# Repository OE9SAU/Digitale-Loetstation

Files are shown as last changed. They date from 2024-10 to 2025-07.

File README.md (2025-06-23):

# Digitale Lötstation mit ATtiny 84 v3

Soldering Unit for Weller RT solder tips.<br>
PCB design by OE9SAU <br>
µC-Code and STL-Desing by OE1CGS [http://www.oe1cgs.at/smd-loetstation/] <br>

v3: Add SK55 for reverse polarity protection

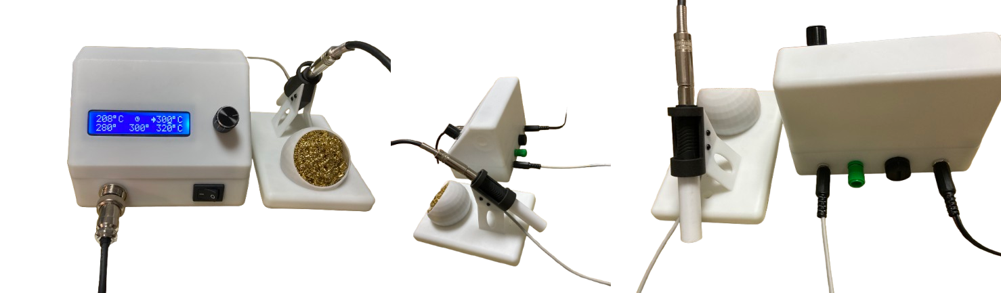
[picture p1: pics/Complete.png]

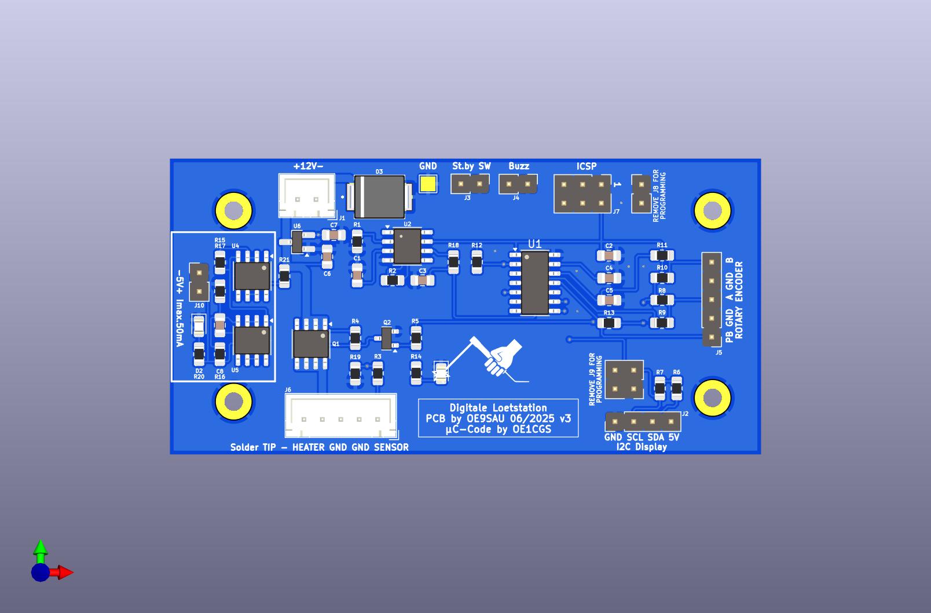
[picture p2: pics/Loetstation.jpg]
SMD-Loetstation

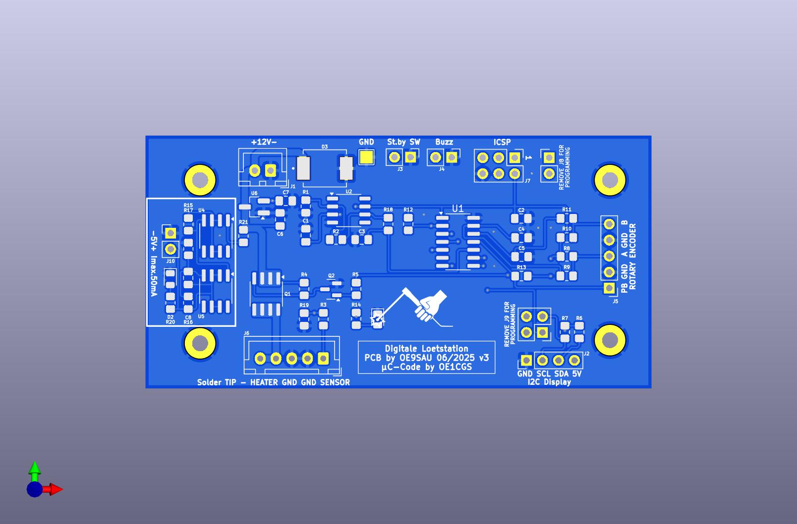
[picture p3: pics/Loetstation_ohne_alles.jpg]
SMD-Loetstation

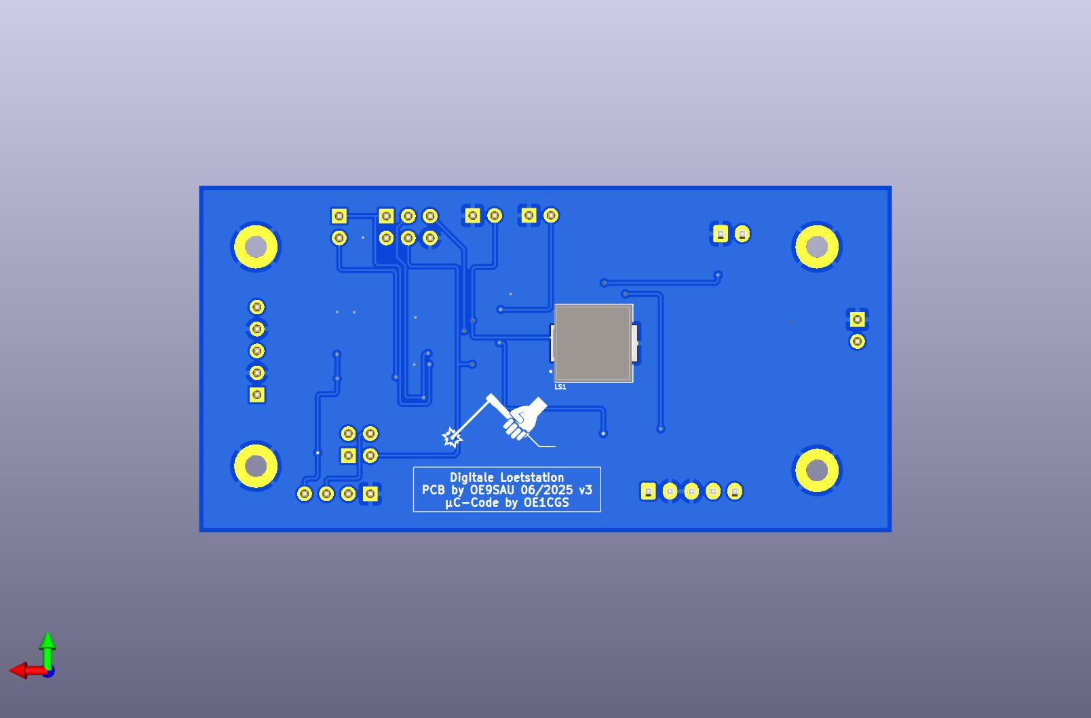
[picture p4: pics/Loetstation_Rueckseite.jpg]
SMD-Loetstation


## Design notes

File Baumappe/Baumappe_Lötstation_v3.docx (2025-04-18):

Baumappe «digitale Lötstation»


1.) Aufbau

Die Lötstation versorgt Lötspitzen der RT-Serie von Weller mit einer PWM-getakteten 12V-Gleichspannung. Das Taktverhältnis wird über die Stellgrößen einer PID-Regelung und der Lötspitzentemperatur, als Regelgröße, gebildet. Der in die Lötspitze integrierte Sensor ermöglicht eine schnelle und direkte Temperaturmessung.

Ein Drehschalter und ein 16x2-LCD mit I2C-Schnittstelle dienen zur Bedienung und Anzeige. Eine Lötspitzenhalterung mit Micro-Schalter aktiviert den Standby-Modus (60°C), um die Lebensdauer der Spitze zu erhöhen. Beim Entnehmen kehrt die Solltemperatur sofort zurück, was auch akustisch signalisiert wird.

Die Steuerung erfolgt über einen ATtiny84. Ein OPA 336V verstärkt die Sensorspannung (680-fach) auf 0 bis 5V für den Mikrocontroller. Der IRF 7416 MOSFET mit einem IRLML2060 als Gate-Treiber, versorgt die Lötspitze mit dem PWM-Signal.

NIEMALS DIE LÖTSPITZE OHNE J8 BETREIBEN!

Die Station benötigt 12V DC bei 3-4A und kann mobil (z. B. Autobatterie) oder stationär mit einem 12V/50W-Netzteil betrieben werden. Eine 4A-Schmelzsicherung bietet Schutz.

2.) Firmware
Die Firmware wurde mit der Arduino IDE für den ATtiny84 von OE1CGS entwickelt. Der Mikrocontroller läuft mit dem internen 1-MHz-RC-Oszillator.

Benötigte Bibliotheken:

- TinyWireM.h (I2C-Master für LCD)
- LiquidCrystal_I2C.h (Display-Steuerung)
- EEPROM.h (Speicherung von Einstellungen)

Der Drehschalter wird Interrupt-gesteuert und als Zustandsmaschine nach Ben Buxton interpretiert.

Funktionen:

- Temperaturregelung per PID (Intervall: 200ms, PWM mit 492Hz)
- Dynamische Anzeige und Einstellung von Parametern
- Standby-Erkennung und automatische Aktivierung
- Speicherung vordefinierter Temperaturen
- Sicherheitsabschaltung bei fehlerhaften Sensordaten (z. B. gelockerte Lötspitze)

3.) Regelungsparameter
Um die Regelungsparameter zu optimieren, wurden an einer Lötspitze vom Typ RT2 umfangreiche Messungen durchgeführt. Dabei wurde die Temperatur in Intervallen von 200 Millisekunden gemessen, zu welchem Zweck die Heizung für jeweils 10 ms ausgeschalten wurde. Damit ergibt sich eine mittlere Heizdauer von 95%.

Diese und weitere Messungen dienten der Kalibrierung eines Simulationsmodells für das Regelverhalten. Eine wesentliche Schlussfolgerung aus den Simulationen war, dass zwar ein einfacher P-Regler für die Lötstation ausreichend wäre, ein PID-Regler aber speziell im Hinblick auf eine rasche Verfügbarkeit (Aufheizphase) überlegen ist.

Die, durch die Simulationen ermittelten Regelungsparameter wurden in die Firmware übernommen und danach im praktischen Einsatz noch etwas adaptiert.

Damit benötigt die Spitze zur Aufheizung von Raumtemperatur auf 260°C nur 3,8 Sekunden; auf 300°C sind es 4,2 s.

Die Regelung hält die Temperatur der unbelasteten Spitze zuverlässig innerhalb +/-2°C. Beim Löten von bedrahteten Bauteilen (THT) sinkt die angezeigte Temperatur nur kurzfristig etwas ab und ist innert einer Sekunde wieder auf der Soll-Temperatur.

4.) Bedienung

Nach dem Einschalten zeigt das Display kurz einen Begrüßungstext und wechselt dann zum Standardschirm. Dort werden die aktuelle Lötspitzentemperatur, der Sollwert und ein Standby-Symbol angezeigt. Im Standby-Modus wird die Temperatur auf 60°C geregelt, um Energie zu sparen und die Lebensdauer der Lötspitze zu verlängern.

Die Solltemperatur kann über drei voreingestellte Werte (220°C, 260°C, 300°C) oder manuell in 1°C-Schritten angepasst werden. Änderungen erfolgen durch Drehen und Drücken des Drehschalters. Die Vorgabewerte lassen sich im Bereich von 60°C bis 400°C individuell speichern.

Beim Einschalten können durch Gedrückt halten des Drehschalters zusätzliche Parameter wie die Vorgabewerte und das akustische Signal angepasst werden. Nach dem Verlassen des Einstellungsmenüs bleiben alle Änderungen im Speicher erhalten.

Bei einem Notstopp durch fehlende Sensordaten erfolgt eine Warnung, und die Lötstation muss neu gestartet werden.

Auf der Rückseite des Geräts befindet sich neben den Anschlüssen für die Stromversorgung und den Standby-Taster sowie dem Sicherungs-halter auch eine Erdungsbuchse. Über diese kann beim Löten die Lötspitze auf das gemeinsame Massepotential gelegt werden. Der Anschluss erfolgt durch einen üblichen 4 mm Bananenstecker.

Schaltplan:

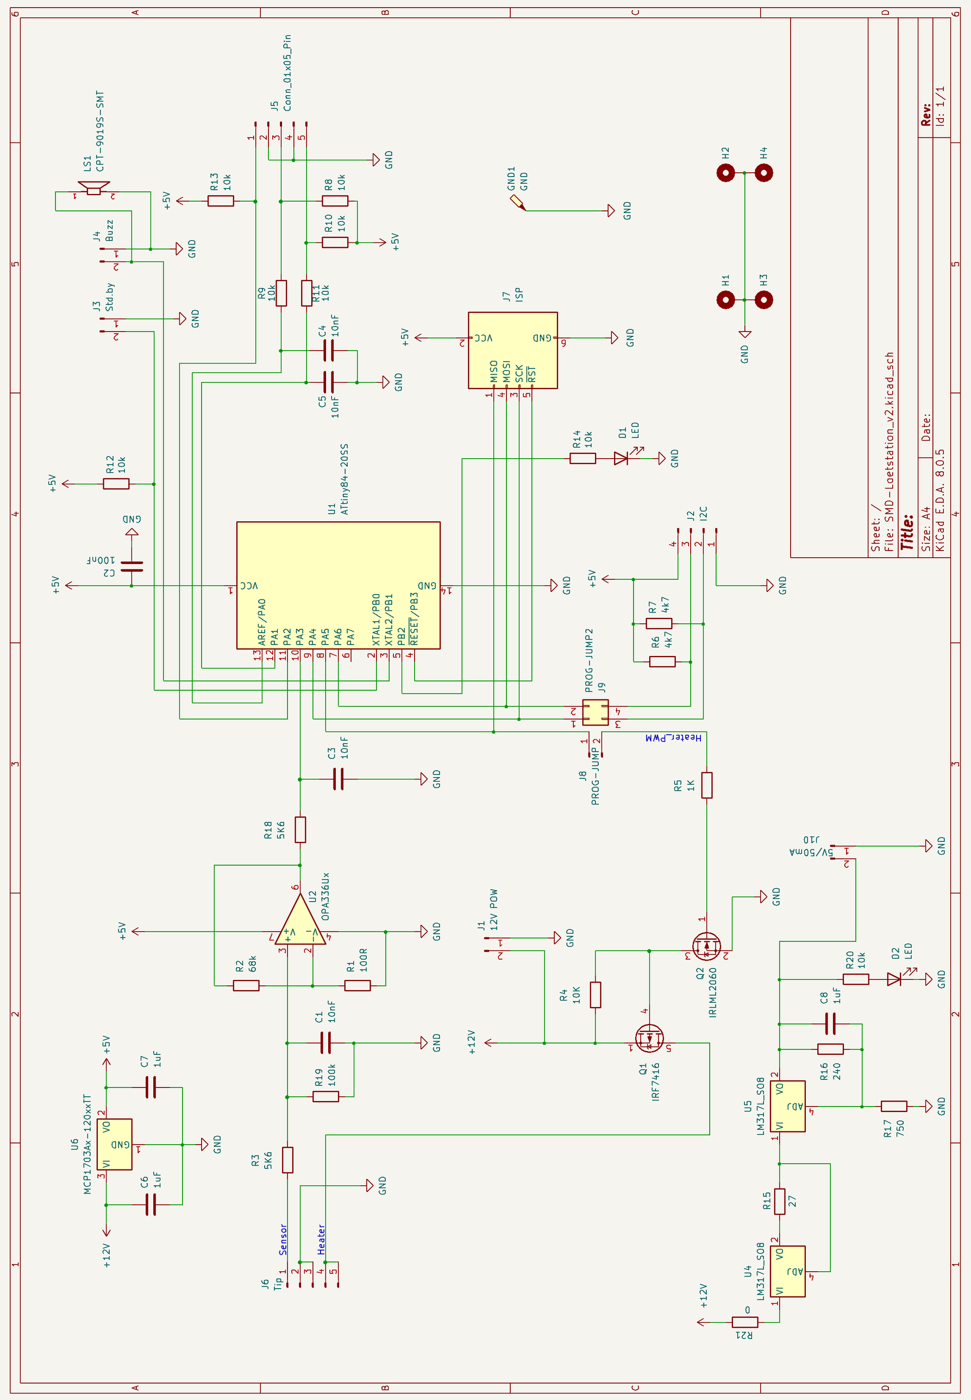
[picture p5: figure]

Bestückungsplan

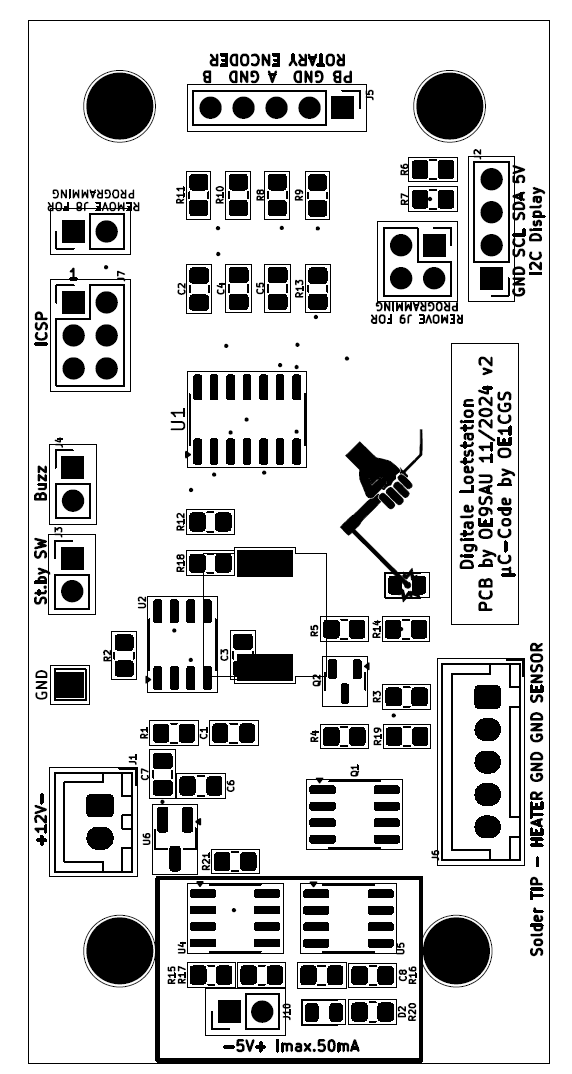
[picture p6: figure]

Stückliste:

Bezeichner | Stückzahl | Bezeichnung
R4,R12,R10,R8,R9,R14,R20,R11,R13 | 9 | 10k
C3,C5,C1,C4 | 4 | 10nF
R3,R18 | 2 | 5K6
R15 | 1 | 27R
R17 | 1 | 750R
J2 | 1 | I2C
R21 | 1 | 0R
R5 | 1 | 1K
Q2 | 1 | IRLML2060
R19 | 1 | 100k
J8 | 1 | PROG-JUMP
J4 | 1 | Buzz
J7 | 1 | ISP
U6 | 1 | MCP1703Ax-120xxTT
U5,U4 | 2 | LM317L_SO8
J1 | 1 | 12V POW
U2 | 1 | OPA336Ux
Q1 | 1 | IRF7416
J10 | 1 | 5V/50mA
R7,R6 | 2 | 4k7
C7,C8,C6 | 3 | 1uF
R2 | 1 | 68k
R1 | 1 | 100R
D1,D2 | 2 | LED
R16 | 1 | 240R
J3 | 1 | Std.by
U1 | 1 | ATtiny84-20SS
J5 | 1 | Conn_01x05_Pin
J6 | 1 | Tip
C2 | 1 | 100nF
J9 | 1 | PROG-JUMP2
Rückseite
LS1 | 1 | CPT-9019S-SMT

Bilder Aufbau:

0.65m Kabel LiYY 4x0.25 (UNITRONIC AMAZON)

Funktion | 4x0.25 | Buchse 4polig | PCB Solder TIP Plug
Sensor | gelb | 1 | 1 / gelb
| | 2 | 2 / leer
GND | weiss | 3 | 3 / schwarz
HEATER | braun/grün | 4 | 4 / braun
| | | 5 / leer

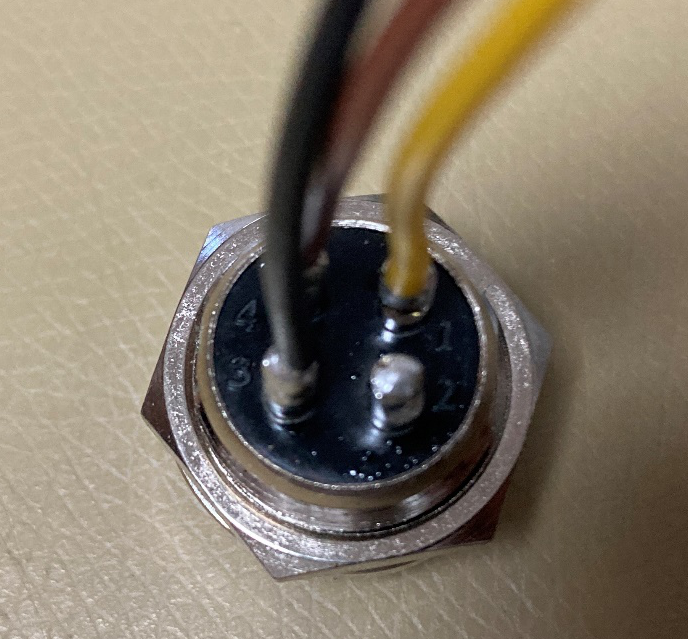
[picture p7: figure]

4 1 3 2

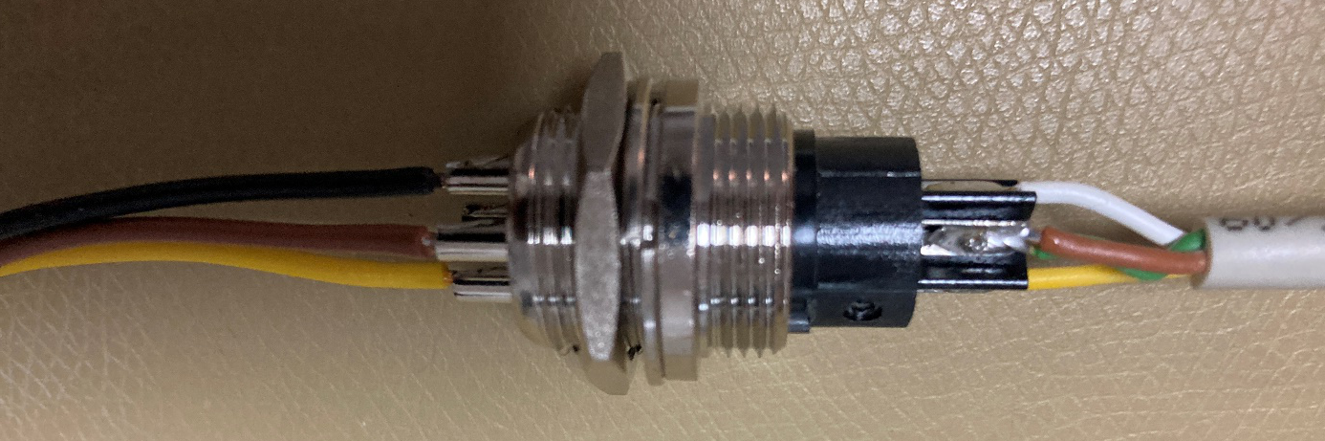
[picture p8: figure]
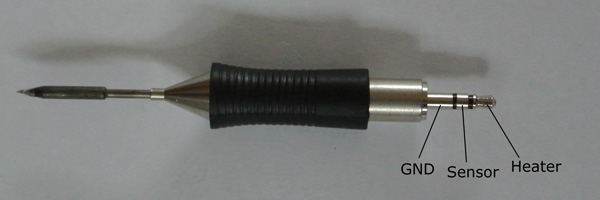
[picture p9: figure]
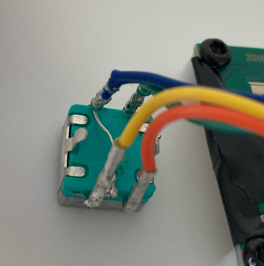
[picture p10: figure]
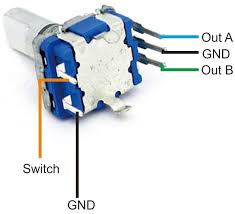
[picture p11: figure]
Rotary encoder not working - General Electronics - Arduino Forum
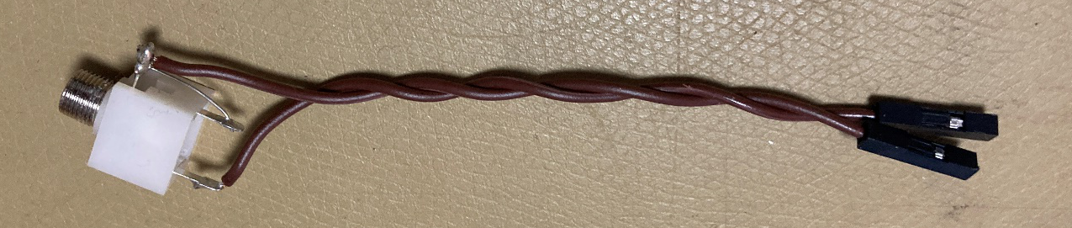
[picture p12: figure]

Wichtig: Brücke

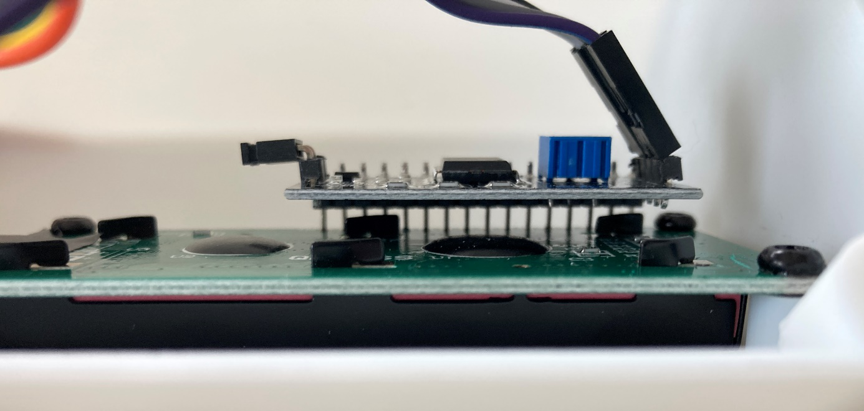
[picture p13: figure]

I2C-Adapter mit dem größtmöglichen (https://www.google.com/search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) Abstand zum LCD anlöten

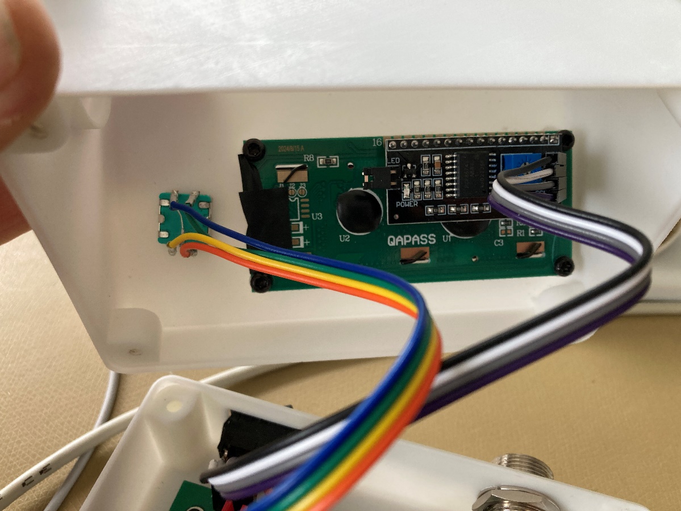
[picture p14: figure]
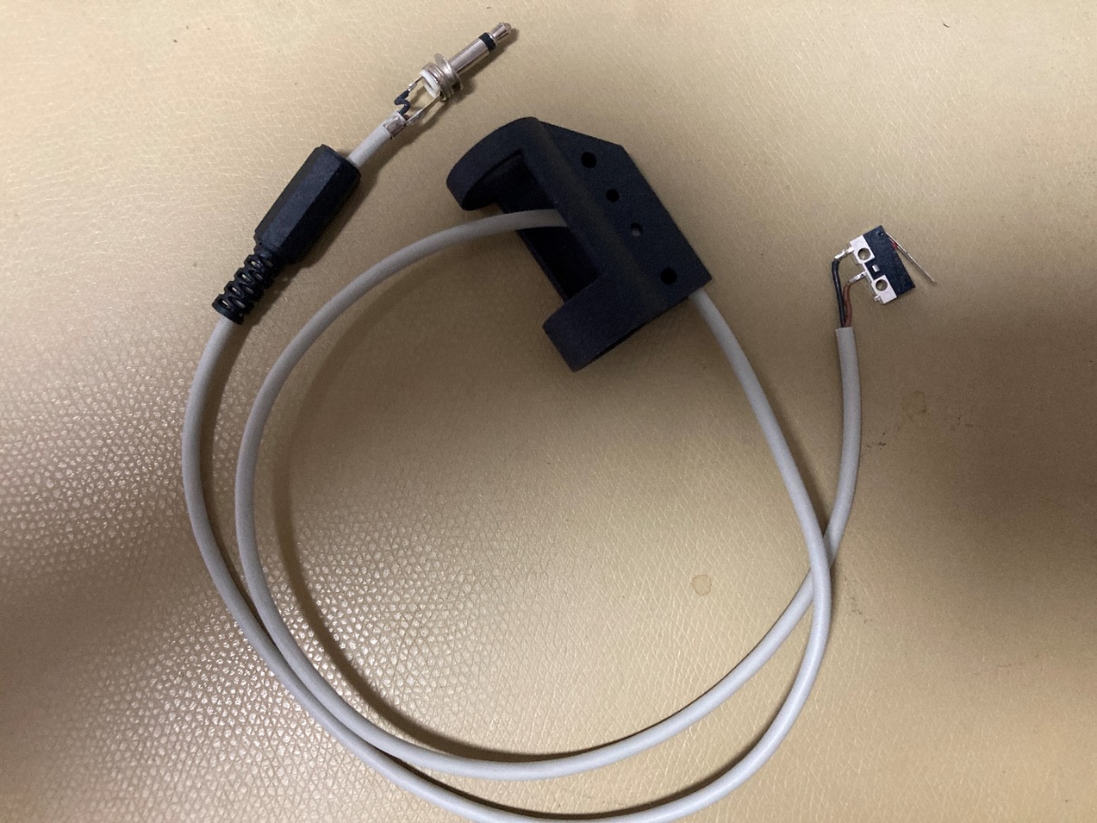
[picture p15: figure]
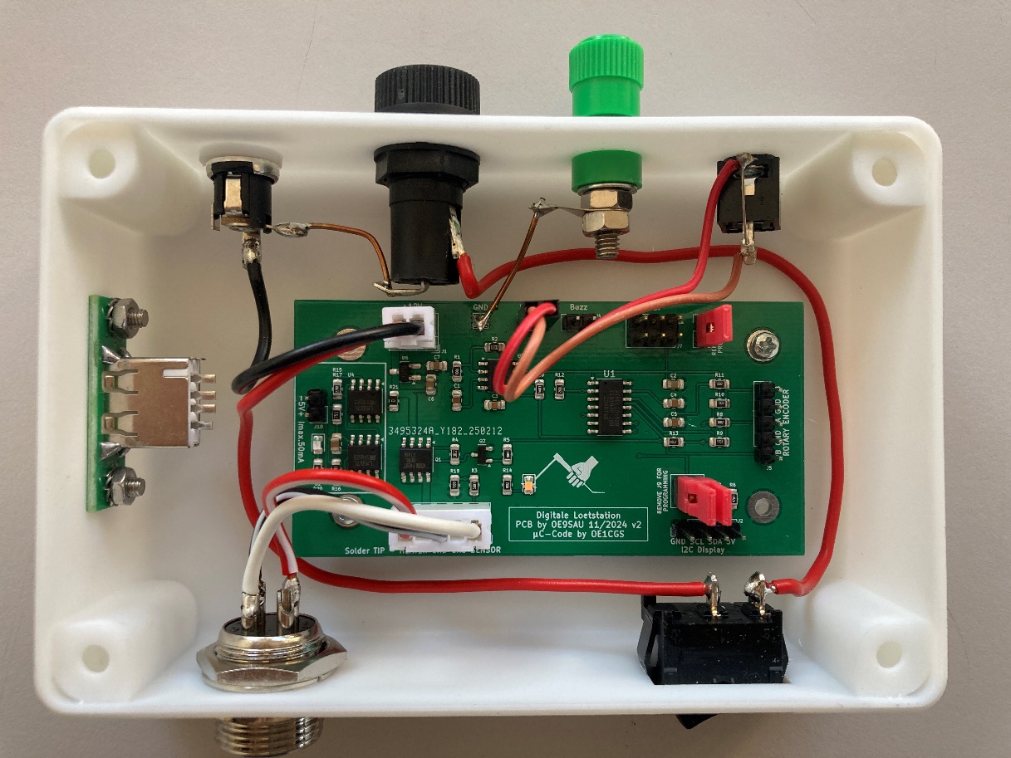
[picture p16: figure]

Quellen:

http://www.oe1cgs.at/wp-content/uploads/2017/09/Loetstation.pdf (Publikation von Christoph OE1CGS)

https://www.thingiverse.com/thing:2521885 (Original STL-Files von Christoph OE1CGS)

https://github.com/OE9SAU?tab=repositories (Programmcode u. STL-Files von OE1CGS, Gerber-Files von Martin OE9SAU)

Seite 1 von 2 18.04.2025, v3, OE9SAU

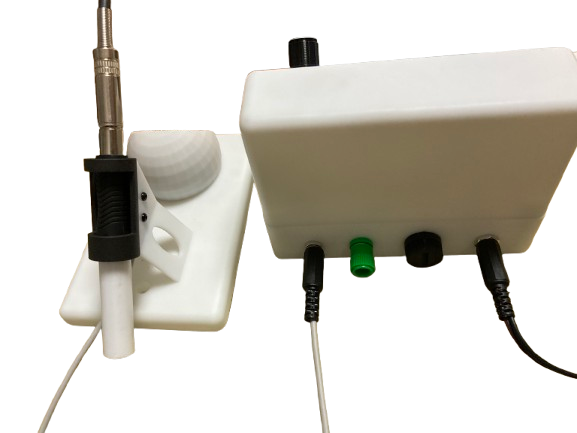
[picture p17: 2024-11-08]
pics/Comp3.png

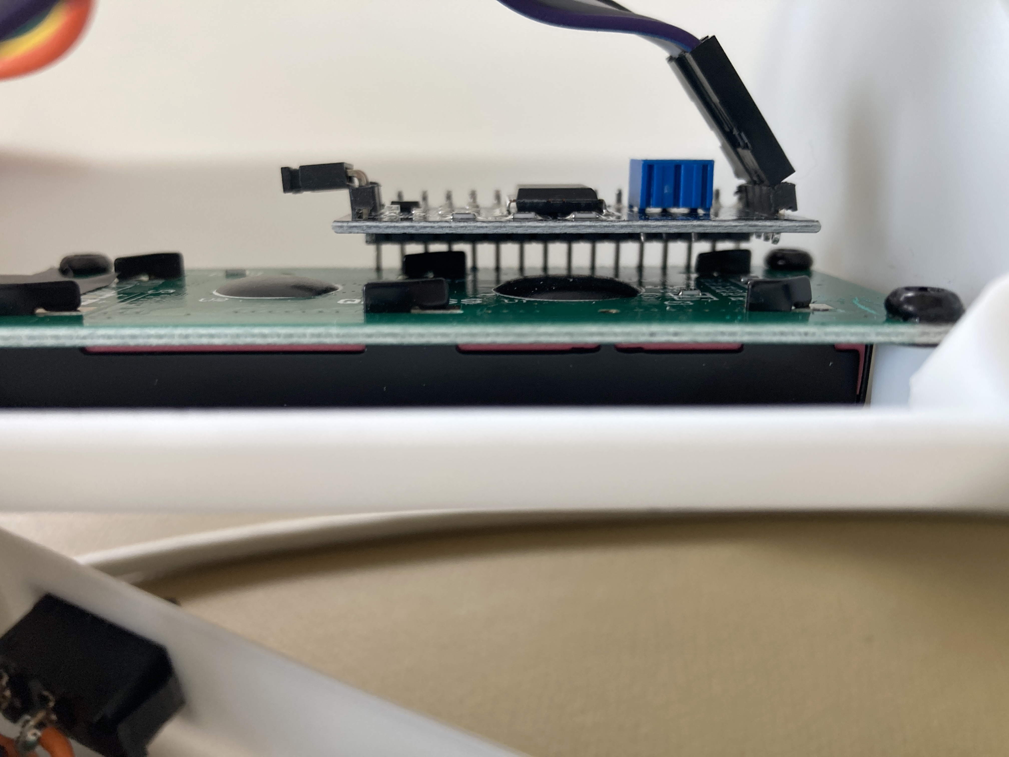
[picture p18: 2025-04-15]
pics/I2C_LCD_Mount.JPG

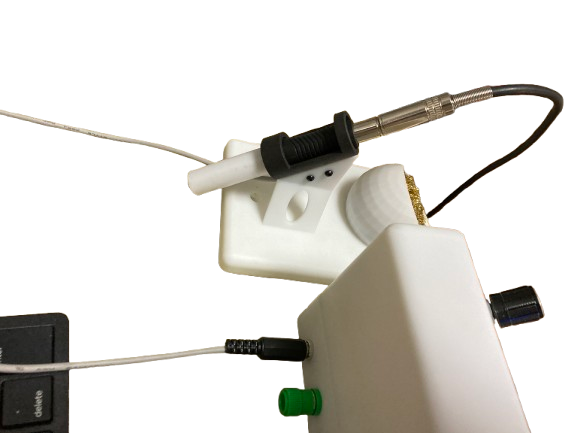
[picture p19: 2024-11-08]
pics/Comp4.png

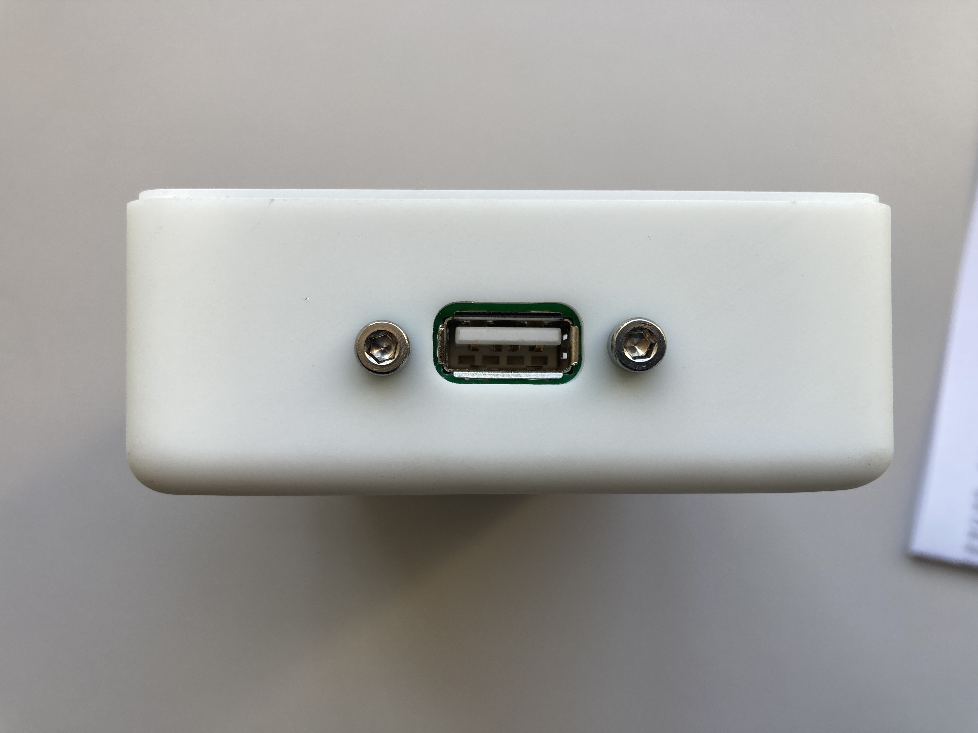
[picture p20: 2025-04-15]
pics/USB_Conenctor.JPG

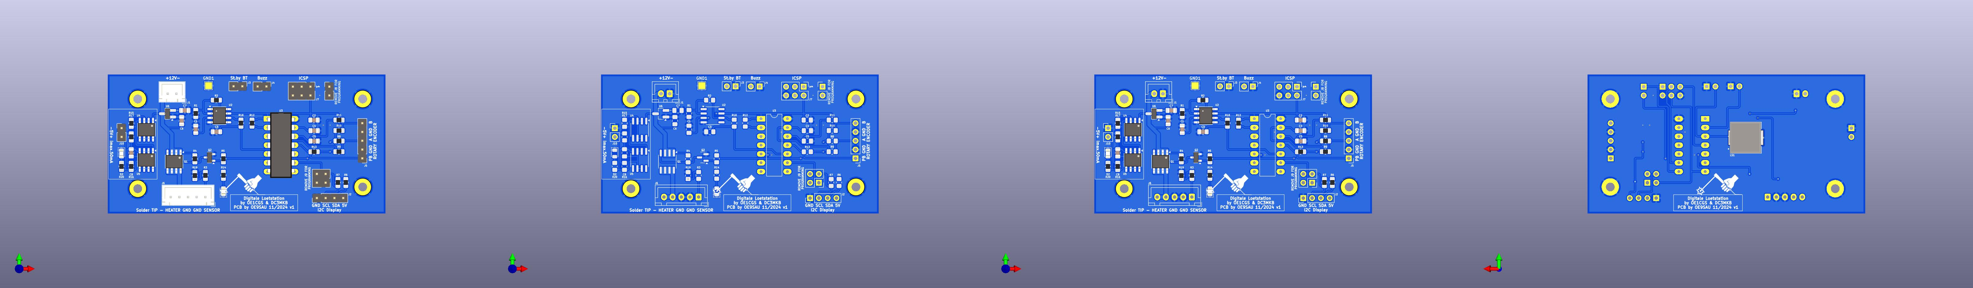
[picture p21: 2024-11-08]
pics/PCB.png

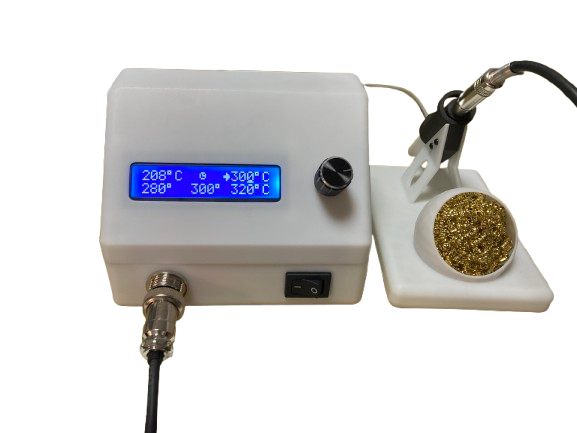
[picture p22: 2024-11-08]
pics/Comp1.png

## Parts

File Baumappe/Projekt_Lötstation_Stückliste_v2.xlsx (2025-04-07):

Bezeichner | Footprint | Stückzahl | Bezeichnung
R4,R12,R10,R8,R9,R14,R20,R11,R13 | R_0805_2012Metric_Pad1.20x1.40mm_HandSolder | 9 | 10k
C3,C5,C1,C4 | C_0805_2012Metric_Pad1.18x1.45mm_HandSolder | 4 | 10nF
R3,R18 | R_0805_2012Metric_Pad1.20x1.40mm_HandSolder | 2 | 5K6
R15 | R_0805_2012Metric_Pad1.20x1.40mm_HandSolder | 1 | 27
R17 | R_0805_2012Metric_Pad1.20x1.40mm_HandSolder | 1 | 750
J2 | PinHeader_1x04_P2.54mm_Vertical | 1 | I2C
R21 | R_0805_2012Metric_Pad1.20x1.40mm_HandSolder | 1 | 0
R5 | R_0805_2012Metric_Pad1.20x1.40mm_HandSolder | 1 | 1K
Q2 | SOT-23 | 1 | IRLML2060
R19 | R_0805_2012Metric_Pad1.20x1.40mm_HandSolder | 1 | 100k
J8 | PinHeader_1x02_P2.54mm_Vertical | 1 | PROG-JUMP
J4 | PinHeader_1x02_P2.54mm_Vertical | 1 | Buzz
J7 | PinHeader_2x03_P2.54mm_Vertical | 1 | ISP
U6 | SOT-23_Handsoldering | 1 | MCP1703Ax-120xxTT
U5,U4 | SOIC-8_3.9x4.9mm_P1.27mm | 2 | LM317L_SO8
J1 | JST_XH_B2B-XH-A_1x02_P2.50mm_Vertical | 1 | 12V POW
U2 | SO-8_3.9x4.9mm_P1.27mm | 1 | OPA336Ux
Q1 | SOIC-8_3.9x4.9mm_P1.27mm | 1 | IRF7416
J10 | PinHeader_1x02_P2.54mm_Vertical | 1 | 5V/50mA
R7,R6 | R_0805_2012Metric_Pad1.20x1.40mm_HandSolder | 2 | 4k7
C7,C8,C6 | C_0805_2012Metric_Pad1.18x1.45mm_HandSolder | 3 | 1uF
R2 | R_0805_2012Metric_Pad1.20x1.40mm_HandSolder | 1 | 68k
R1 | R_0805_2012Metric_Pad1.20x1.40mm_HandSolder | 1 | 100R
D1,D2 | LED_0805_2012Metric | 2 | LED
R16 | R_0805_2012Metric_Pad1.20x1.40mm_HandSolder | 1 | 240
GND | TestPoint_Pad_2.0x2.0mm | 1 | GND
J3 | PinHeader_1x02_P2.54mm_Vertical | 1 | Std.by
U1 | SOIC-14_3.9x8.7mm_P1.27mm | 1 | ATtiny84-20SS
J5 | PinHeader_1x05_P2.54mm_Vertical | 1 | Conn_01x05_Pin
J6 | JST_XH_B5B-XH-A_1x05_P2.50mm_Vertical | 1 | Tip
C2 | C_0805_2012Metric_Pad1.18x1.45mm_HandSolder | 1 | 100nF
J9 | PinHeader_2x02_P2.54mm_Vertical | 1 | PROG-JUMP2
LS1 | CUI_CPT-9019S-SMT | 1 | CPT-9019S-SMT

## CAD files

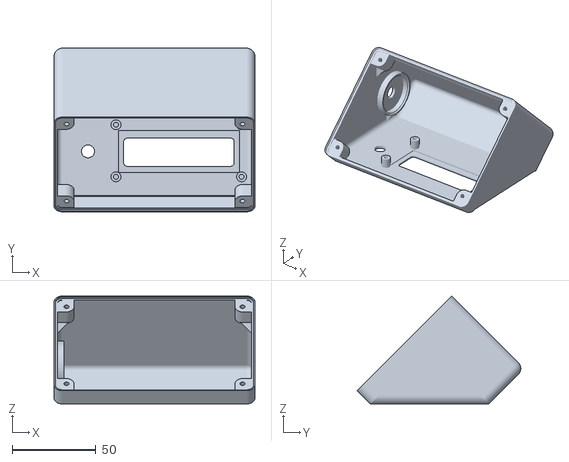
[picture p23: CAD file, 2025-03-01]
stl-files/by_OE1CGS/Soldering_station_top.stl
120.0 x 97.7 x 64.5

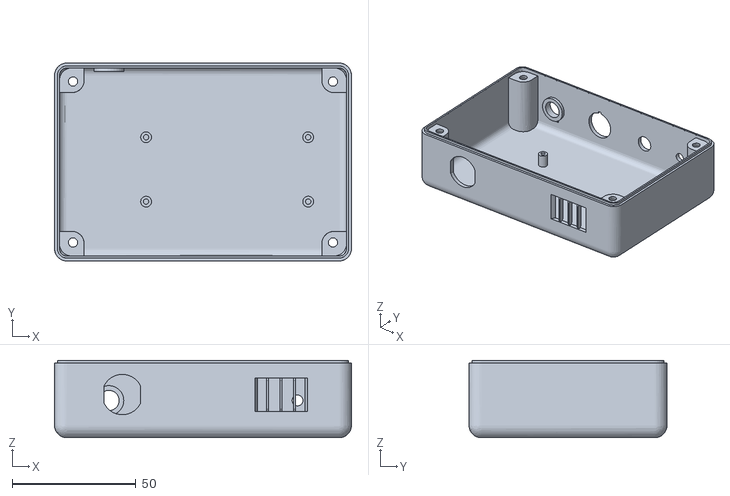
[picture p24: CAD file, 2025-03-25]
stl-files/v1/Soldering_station_bottom_V1.stl
120.0 x 80.0 x 31.3

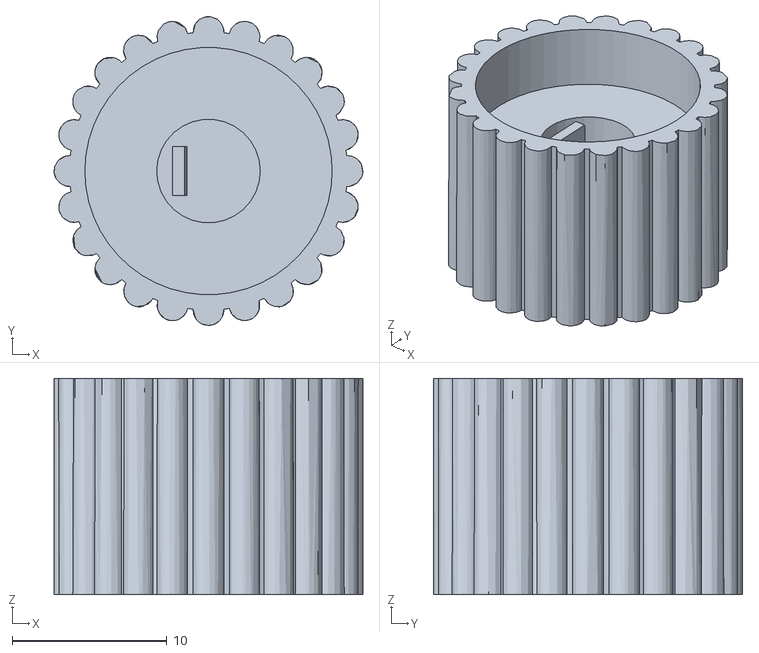
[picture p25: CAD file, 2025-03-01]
stl-files/by_OE1CGS/Rotary_dial_button.stl
20.0 x 20.0 x 14.0

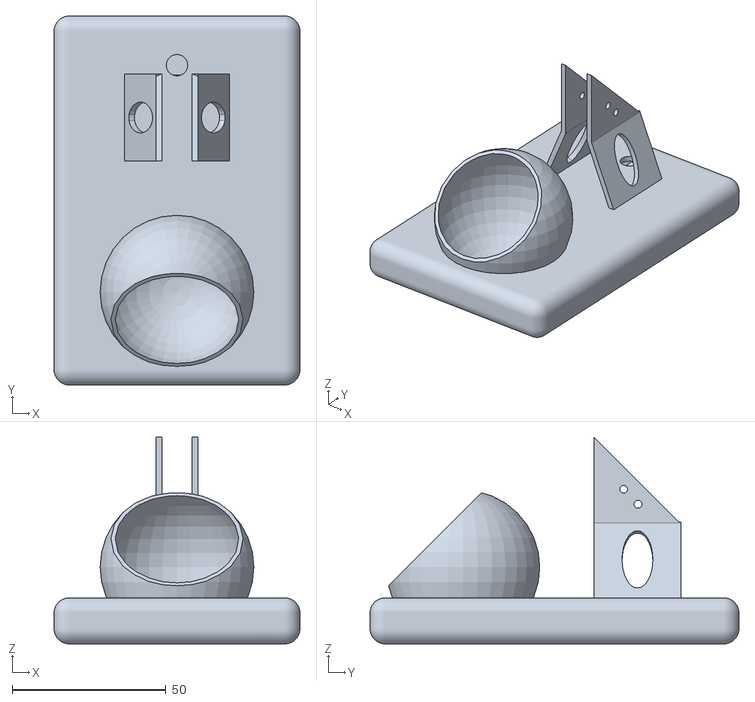
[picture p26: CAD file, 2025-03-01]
stl-files/v1/Tip_holder_bottom_V1.stl
80.0 x 120.0 x 67.3

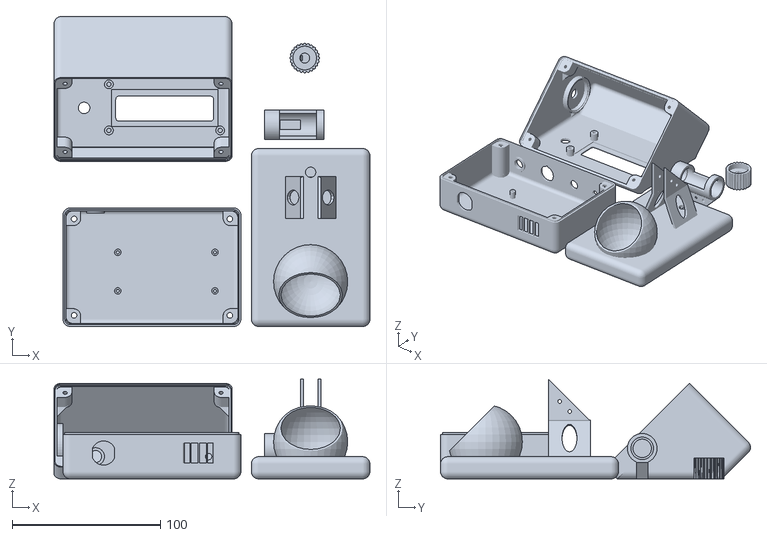
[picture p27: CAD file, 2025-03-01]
stl-files/by_OE1CGS/soldering_station.stl
213.0 x 209.0 x 67.3

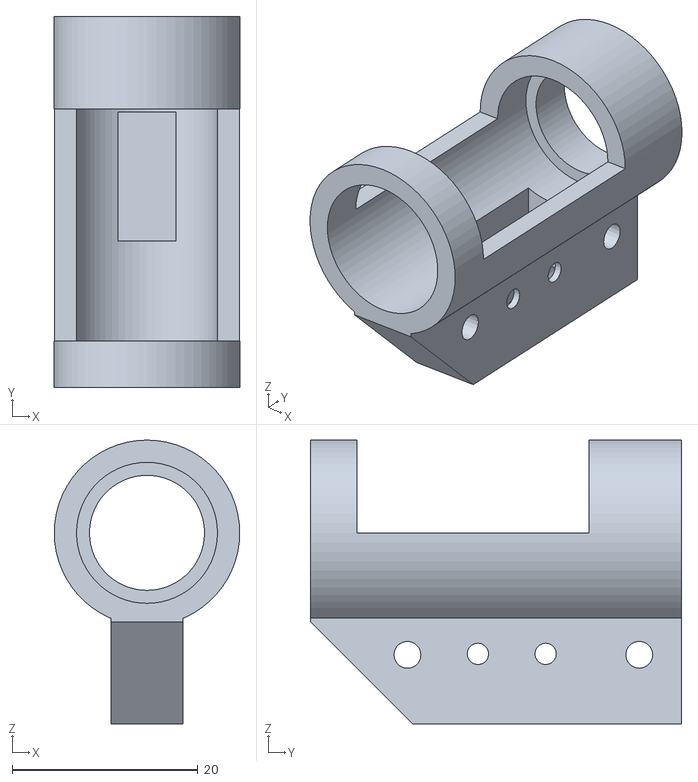
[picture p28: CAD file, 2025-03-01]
stl-files/v1/Tip_holder_top.stl
20.0 x 40.0 x 30.6

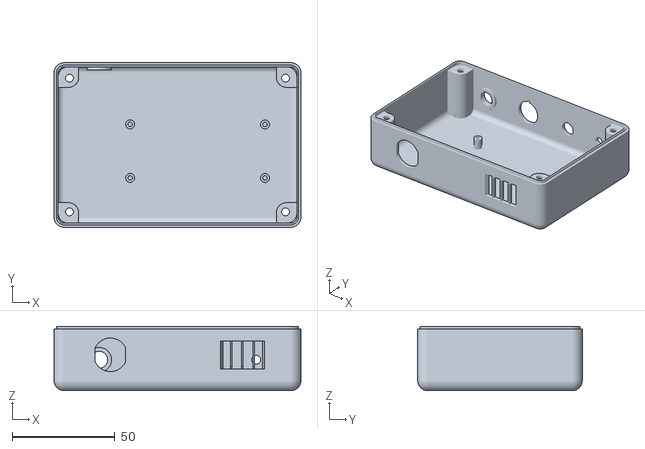
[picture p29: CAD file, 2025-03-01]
stl-files/by_OE1CGS/Soldering_station_bottom.stl
120.0 x 80.0 x 31.3

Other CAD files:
stl-files/by_OE1CGS/Tip_holder_bottom.stl

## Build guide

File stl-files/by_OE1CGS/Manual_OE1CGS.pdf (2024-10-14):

# Digitale Lötstation mit ATtiny 84

# Christoph Schwärzler, OE1CGS

# September 2017

Abstract

Manual soldering of surface mounted parts requires among other skills good tools. Unfortunately professional soldering stations for SMD come with a hefty price tag. However it is possible to build such a professional tool for little money. As M. Kumm, DC3MKB pointed out, Weller sells their professional soldering tips RT1 to RT4 as replacement parts for around 40 €¹
. They are
connected by a standard 3.5 mm stereo plug, so it is possible to use those tips on top of a self-bred microcontroller based station.

In contrast to M. Kumm’s original project the device presented in this article uses a LCD to provide detailed information such as actual, target and default temperatures. Three different default temperatures can be adjusted to one’s own needs and stored permanently. Standby mode is indicated on the display and a buzzer sounds when the target temperature is reached for the first time. Despite these additional functionality there is less hardware required. For example the Arduino microcontroller is replaced by a simple ATtiny 84 using an internal oscillator.

Finally a bespoke casing is presented which allows for a convenient assembly of all parts. The casing can be printed on a standard 3D-printer.

Zusammenfassung

Das manuelle Löten von SMD-Bauteilen stellt auch einige Anforderungen an das Lötwerkzeug. Leider sind professionelle SMD-Lötstationen nach wie vor relativ teuer. Wie M. Kumm, DC3MKB aufgezeigt hat, ist es allerdings auch möglich eine derartige Station mit vernünftigem Aufwand selbst zu bauen. Einen guten Ausgangspunkt dafür stellen die Lötspitzen RT1 bis RT4 von Weller dar, die als Verbrauchsmaterial auch einzeln für rund 40 € verkauft werden. Da sie über einen Standard 3,5 mm Stereostecker verfügen, können sie zusammen
mit | einer | selbstgebauten, | mikrocontroller-
gesteuerten Basiseinheit betrieben werden.

In Ergänzung zu M. Kumm’s Projekt verfügt das in diesem Artikel vorgestellte Gerät über eine LC-Anzeige für die IST- und SOLL-Temperatur sowie 3 definierbare Temperaturen. Deren Werte können dauerhaft gespeichert werden. Der Standby-Betrieb wird optisch und das erstmalige Erreichen der SOLL-Temperatur zusätzlich akustisch angezeigt. Dennoch sinkt der Hardwareaufwand sogar, denn an Stelle eines Arduino kommt hier ein einfacher, intern getakteter ATtiny 84 zum Einsatz.

Zur leichteren Montage der Komponenten wurde ein spezielles Gehäuse entworfen. Es lässt sich mit geringem Aufwand auf einem handelsüblichen 3D-Drucker herstellen.

1.) Aufbau

Das Konzept wird hier nur kurz beschrieben, da M.
Kumm | dieses | schon | in | diversen | Artikeln
veröffentlicht hat¹,2,3
. Dort finden sich auch
Schaltpläne für die Peripheriekomponenten.

Die Lötstation versorgt die Lötspitze mit einer PWM-getakteten Gleichspannung von 12 V. Das Taktverhältnis bildet die Stellgröße einer PID-
Regelung | mit | der | Spitzentemperatur | als
Regelgröße. Durch den bereits in die Lötspitze integrierten Sensor ist dieser Wert leicht zugänglich. Mittels Drehschalter und LCD kann der Benutzer wesentliche Daten ablesen, verändern und Voreinstellungen dauerhaft abspeichern. Zur Lötstation gehört auch eine Ablage für die Lötspitze mit integriertem Schalter. Dieser aktiviert bei nicht benutzter Spitze den Standby-Modus, welcher durch eine Absenkung der Solltemperatur auf 60°C eine deutliche Verlängerung der Lebensdauer bewirkt. Bei Entfernung der Lötspitze aus der Ablage wird sofort wieder die ursprüngliche Solltemperatur angefahren und deren Erreichung auch akustisch angezeigt. Bild 1 stellt die gesamte Lötstation dar.

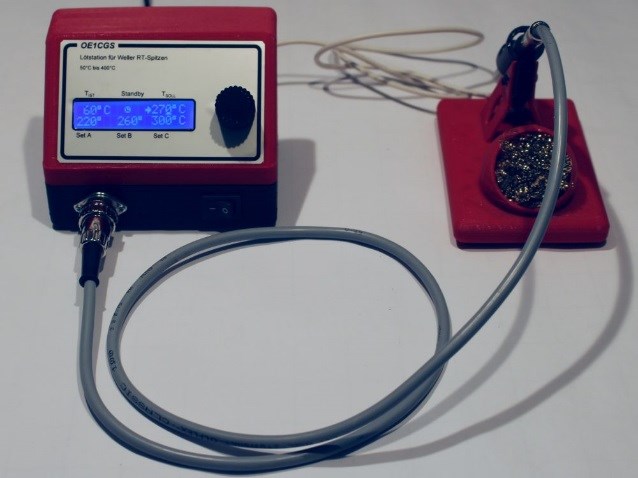
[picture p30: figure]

Bild 1: Digitale Lötstation inklusive Lötspitzenhalter

Die gesamte Steuerung der Lötstation erfolgt durch einen einfachen Mikrocontroller ATtiny 84 von Atmel⁴

. Das zweizeilige LC-Display⁵
, basierend auf
dem HD44780 Controller mit 16 Zeichen pro Zeile verfügt über ein integriertes I2C Interface und kann daher mit nur zwei Datenleitungen angesprochen werden. Der Drehschalter⁶
(2-bit Gray Code) weist
20 Rastungen pro Umdrehung sowie einen Drucktaster auf.

Als | komplexe | I/O-Erweiterungen | für | den
Mikrocontroller kommen im Wesentlichen zwei
Bausteine | zum | Einsatz. | Einerseits | ein
Operationsverstärker vom Typ OPA 336V der so beschalten wird, dass er mit einer 680-fachen
Verstärkung | die | Ausgangsspannung | des
Temperaturfühlers der Lötspitze auf den A/D-Bereich von 0 bis 5 V des Controllers bringt. Andererseits wurde rund um einen Leistungs-MOSFET vom Typ IRF 7416 die Endstufe zur Versorgung der Lötspitze mit der PWM getakteten Versorgung von 12 V und einem Strom von bis zu 10 A realisiert. Diese SMT-Bauteile sind auf eine einseitig kaschierte und geätzte Kupferplatine montiert (Bild 2). Dank der einfachen Strukturen genügt es dazu, vor dem Ätzen die zu erhaltenden Kupferflächen mit zugeschnittenem Isolierband abzudecken.

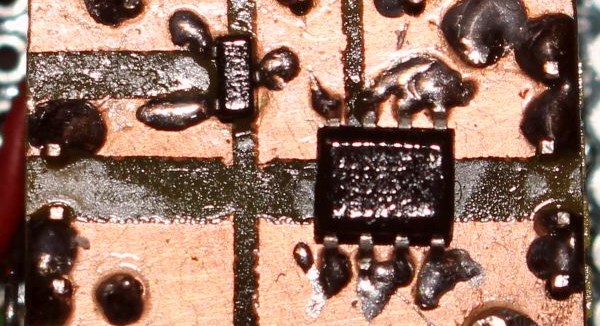
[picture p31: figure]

Bild 2: Einfache Platine mit gelöteten SMT-Bauteilen

Ein normal offener Taster zur Feststellung des Standby-Betriebs und ein Piezo-Schallwandler als akustisches Signal ergänzen die benötigten Komponenten.

Die | gesamte | Elektronik | ist | auf | einer
Lochrasterplatine realisiert, wobei die einzelnen Komponenten über 2,54 mm Steckerleisten angeschlossen werden (Bild 3). Der Mikrocontroller sollte mittels entsprechender IC-Fassung integriert werden.

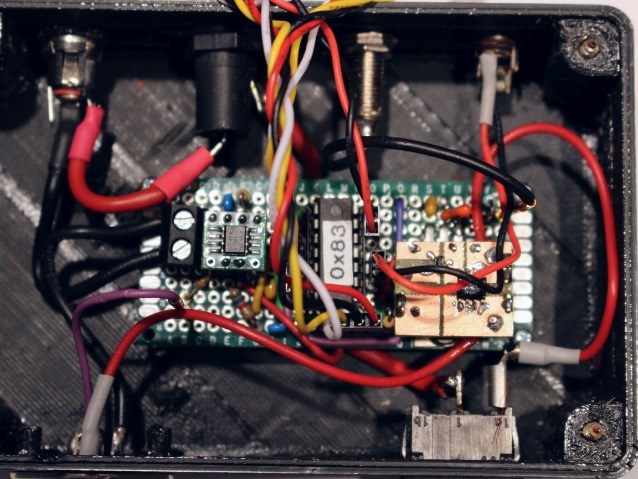
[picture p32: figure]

Bild 3: Aufbau der Schaltung aus den Komponenten auf einer Lochrasterplatine

Die Station muss mit einer Gleichspannung von 12 V bis 14 V bei einer Strombelastbarkeit von 5 A versorgt werden. Sie kann daher z.B. direkt an einer Autobatterie betrieben werden. Für den stationären Einsatz empfiehlt sich ein externes 12V Netzgerät mit einer Leistung ab 50 Watt. Die Lötstation wird intern mit einer trägen 4 A Schmelzsicherung geschützt.

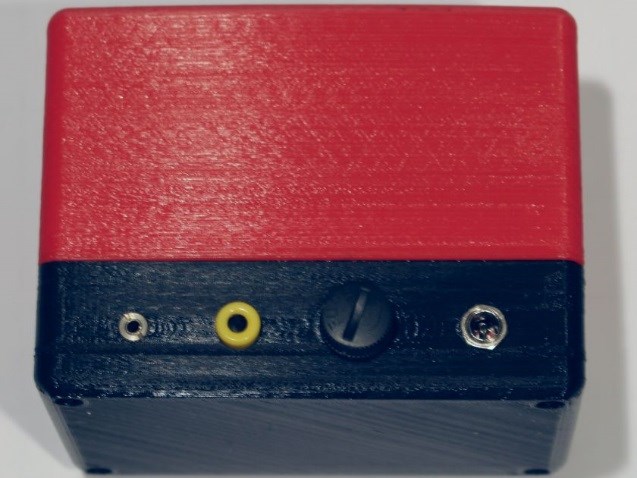
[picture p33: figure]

Bild 4: Rückseite mit den Anschlüssen (v.l.n.r): Standby-Taster, Erdungsbuchse, Sicherungshalter, Versorgungsspannung

Auf der Rückseite des Geräts (Bild 4) befindet sich neben den Anschlüssen für die Stromversorgung und den Standby-Taster sowie dem Sicherungshalter auch eine Erdungsbuchse. Über diese kann als EMV-Maßnahme beim Löten die Lötspitze auf das gemeinsame Massepotential gelegt werden. Der Anschluss erfolgt durch einen üblichen 4 mm Bananenstecker.

Gehäuse (optional)

Sowohl das Gehäuse für die Elektronik als auch die
Lötspitzenhalterung | wurden | mit | einem
handelsüblichen 3D-Drucker mit PLA erstellt⁷
. Sie
bestehen jeweils aus 2 Teilen, die mit Schrauben aneinander befestigt werden. Der Unterteil der Lötstation verfügt bereits über Halterungen für die Montage einer 30x70 mm Lochrasterplatte und die Ausnehmungen für die Anschlüsse und den
Sicherungshalter. | Der | Oberteil | hat | die
Ausnehmungen und Montagemöglichkeiten für die LC-Anzeige und den Drehschalter. Die Halterung für die Lötspitze ist hohl und sollte zur Erhöhung der Stabilität über das vorhandene Loch z. B. mit Wasser befüllt werden. Die halbkugelförmige
Halterung | dient | der | Aufnahme | einer
Lötspitzenreinigung wie z.B. Messingwolle. In die
eigentliche | Halterung | (Oberteil) | wird | der
Mikroschalter für die Standby-Funktion sowie ein Schutz aus einem 45 mm langen Stück Edelstahlrohr mit 12 mm Durchmesser eingebaut.

2.) Firmware

Die Firmware wurde auf der Arduino IDE Version 1.6.12 für den ATtiny 84 entwickelt. Sie kann unter der GNU GPL genutzt werden und ist auf meiner Website verfügbar⁸
. Zum Compilieren wurde der ATtiny Core von David Melles benutzt⁹
. Um den
Hardwareaufwand möglichst gering zu halten, wird der Mikrocontroller mit dem internen RC-Oszillator bei einer Taktrate von 1 MHz betrieben.

Für eine erfolgreiche Programmierung werden die drei folgenden Bibliotheken benötigt:

- TinyWireM.h
- LiquidCrystal_I2C.h
- EEPROM.h

TinyWireM stellt einen I2C-Master zur Verfügung, welcher für die Ansteuerung des LC-Displays erforderlich ist. Für die Anzeigen auf dem Display stellt LiquidCrystal_I2C viele Routinen bereit und EEPROM ist für das Schreiben und Lesen des nichtflüchtigen Speichers erforderlich.

Der Drehschalter wird interrupt-gesteuert als Zustandsmaschine nach dem Schema von Ben Buxton¹⁰ interpretiert.

Die wesentlichen Funktionen der Firmware sind neben der Temperaturregelung der Lötspitze die dynamische Anzeige und Änderungsmöglichkeit der Betriebsparameter, die Erkennung und Umsetzung des Standby-Betriebs, die optionale akustische Information über die Betriebsbereitschaft sowie die Handhabung und dauerhafte Speicherung vordefinierter Temperaturwerte.

Die Temperaturregelung erfolgt nach dem PID-Verfahren in Intervallen von 200 Millisekunden. Die geregelte Größe ist die Pulsweite eines mit 492 Hz betriebenen PWM-Digitalausgangs, der über einen Leistungstransistor (MOSFET, IRF 7416) die Versorgung ein- und ausgetastet an die Lötspitze weiterleitet. Die Messgröße ist die Spannung des in die Lötspitze eingebauten Thermoelements mit
einer | 680-fachen | Verstärkung | über | einen
Operationsverstärker (OPA 336U). Die derart verstärkte Spannung ist im Temperaturbereich von
Raumtemperatur | bis | 450°C | annähernd
proportional¹¹ der Temperatur und nimmt Werte von Null bis Versorgungsspannung (5V) an. Sie wird dem 10-bit A/D Wandler des Mikrocontrollers zugeführt.

Werden vom Temperatursensor keine sinnvollen Werte mehr erhalten (z. B. weil sich die Lötspitze etwas aus der Buchse bewegt hat), so wird die Heizung innerhalb einer halben Sekunde abgeschaltet.

Die Firmware benötigt in der aktuellen Version 1.2 einen Programmspeicher von 6690 Byte (verfügbar: 8192 Byte) und einen Variablenspeicher von 258 Byte (512 Byte). Außerdem werden 7 Bytes des
EEPROM-Speichers | dazu | benutzt, | um | die
Einstellparameter auch nach einer Unterbrechung der Versorgungsspannung zu erhalten.

3.) Regelungsparameter

Um die Regelungsparameter zu optimieren, wurden an einer Lötspitze vom Typ RT2 umfangreiche Messungen durchgeführt. Beispielhaft zeigt Bild 5 den Temperaturverlauf während und nach einer 3 Sekunden langen Erhitzung durch Anschluss an 10,8 V.

Dabei wurde die Temperatur in Intervallen von 200 Millisekunden gemessen, zu welchem Zweck die Heizung für jeweils 10 ms ausgeschalten wurde. Damit ergibt sich eine mittlere Heizdauer von 95%.

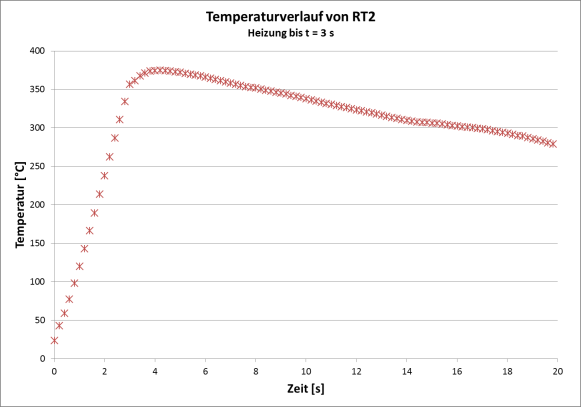
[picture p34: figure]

Bild 5: Temperaturverlauf einer Lötspitze RT2 bei 95% Heizleitung für

### 3 Sekunden und anschließender passiver Abkühlung

Diese und weitere Messungen dienten der Kalibrierung eines Simulationsmodells für das Regelverhalten. Eine wesentliche Schlussfolgerung aus den Simulationen war, dass zwar ein einfacher P-Regler für die Lötstation ausreichend wäre, ein PID-Regler aber speziell im Hinblick auf eine rasche Verfügbarkeit (Aufheizphase) überlegen ist.

Die, | durch | die | Simulationen | ermittelten
Regelungsparameter wurden in die Firmware übernommen und danach im praktischen Einsatz noch etwas adaptiert. Damit benötigt die Spitze zur Aufheizung von Raumtemperatur auf 260°C nur 3,8 Sekunden; auf 300°C sind es 4,2 s. Die Regelung hält die Temperatur der unbelasteten Spitze zuverlässig innerhalb ±2°C. Beim Löten von üblichen bedrahteten Bauteilen sinkt die angezeigte Temperatur nur extrem kurzfristig etwas ab und ist
innerhalb | einer | Sekunde | wieder | auf | der
Solltemperatur.

4.) Bedienung

Nach dem Einschalten erscheint auf der Anzeige für 2 Sekunden ein Begrüßungstext inklusive der
Versionsnummer | der | aktuellen | Firmware.
Unmittelbar | danach | wechselt | die | Anzeige
automatisch auf den Standardschirm (Bild 6).

Auf diesem wird in der oberen Zeile links die aktuelle Temperatur der Lötspitze in Grad Celsius angezeigt. In der Mitte erscheint ein Uhrensymbol sobald die Lötspitze in die Halterung gelegt und damit der Standby-Modus aktiviert wird. Im Standbybetrieb wird unabhängig vom gerade eingestellten Sollwert auf eine Temperatur von 60°C geregelt. Dies senkt den Stromverbrauch und erhöht vor allem die Lebensdauer der Lötspitze erheblich. Im rechten Teil der oberen Zeile wird
hinter | einem | Pfeil | die | gerade | gewählte
Solltemperatur angezeigt. Unmittelbar nach dem Einschalten beträgt diese aus Sicherheitsgründen immer 60°C.

In der unteren Zeile leuchten drei Vorgabewerte für die Solltemperatur. Sie sind im Permanentspeicher der Lötstation abgelegt und bleiben daher auch nach dem Ausschalten erhalten.

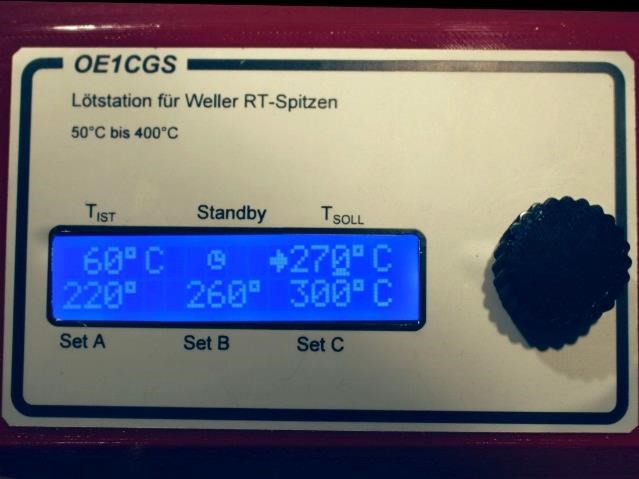
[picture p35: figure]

Bild 6: Anzeige mit aktueller Temperatur und Solltemperatur, Standby-Indikator und einer Auswahl an frei konfigurierbaren Solltemperaturen

Die Auswahl einer dieser Vorgabewerte erfolgt sehr einfach durch Drehung des Drehschalters, wodurch eine Markierung (nach dem Einschalten unter der letzten Ziffer der Solltemperatur angezeigt) zwischen den drei Vorgabewerten und der Solltemperatur bewegt werden kann. Befindet sich diese Markierung unter dem gewünschten Wert, kann dieser durch einfaches Drücken des

Drehschalters als neuer Sollwert übernommen werden und die Regelung stellt sich sofort auf die neue Vorgabe ein.

Zusätzlich kann die aktuelle Solltemperatur in 1°C-Schritten auf jeden gewünschten Wert eingestellt werden. Dazu muss sich die Markierung unter der Solltemperatur befinden und der Drehschalter gedrückt werden. Wird nun bei weiterhin gedrücktem Drehschalter dieser nach links oder rechts bewegt, so wird die Solltemperatur gesenkt oder erhöht. Die Regelung folgt unmittelbar jedem neuen Wert. Bei Erreichen des gewünschten Sollwertes wird der Drehschalter losgelassen.

Die drei Vorgabewerte sind standardmäßig auf 220°C, 260°C und 300°C gesetzt, lassen sich aber vom Benutzer beliebig im Arbeitsbereich der Lötstation von 60°C bis 400°C festlegen. Dazu muss der Drehschalter während des Einschaltens der Station gedrückt gehalten werden. Er kann losgelassen werden, wenn nach wenigen Sekunden an Stelle des Standardschirms der Schirm für die Parametereinstellungen (Bild 7) erscheint.

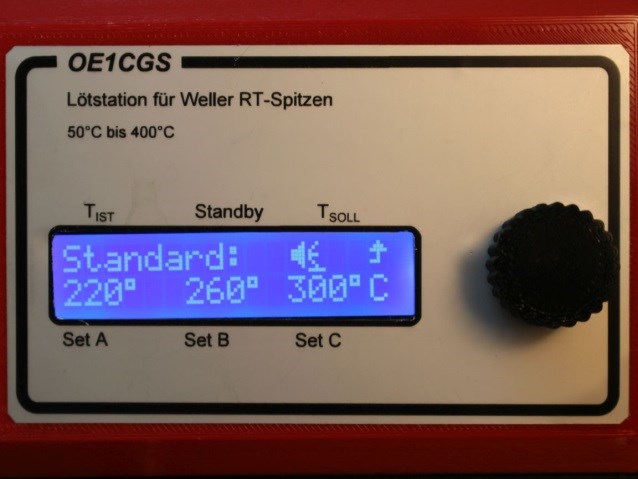
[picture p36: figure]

Bild 7: Anzeige zur Einstellungen der Parameter. Diese erscheint, wenn während des Einschaltvorgangs der Lötstation der Drehschalter gedrückt gehalten wird.

Neben den 3 Vorgabewerten kann hier das akustische Signal ein- bzw. ausgeschalten werden. Dazu wird die Markierung (Unterstreichung) auf den gewünschten Wert bewegt und dieser dann bei gedrücktem Drehschalter durch Schalterdrehung verändert. Nach dem Verlassen der Einstellungen durch Bewegung der Markierung unter das Rechts-Pfeil-nach-oben Symbol und Betätigung des Druckschalters gelangt der Benutzer zurück in das Standardmenü (Bild 6). Sämtliche Einstellungen werden bei Verlassen der Einstellungen in den nichtflüchtigen Speicher übernommen und stehen damit dauerhaft zur Verfügung, können jedoch auch jederzeit erneut geändert werden.

Bei einem Notstop durch fehlende Temperatursensordaten (siehe Abschnitt 2) wird ein akustisches Warnsignal ausgegeben und auf der Anzeige „WARNUNG Lötspitze“ dargestellt. Nach der Behebung der Fehlerquelle muss die Lötstation durch Aus- und Wiedereinschalten neu gestartet werden.

5.) Aufwand und Bauteileliste

Der Bauteilaufwand für die Lötstation selbst ist sehr gering und die Kosten dafür belaufen sich auf rund 10 bis 20 €. Für die Lötspitzen muss allerdings mit einem Preis von rund 40 € gerechnet werden.

Für den Aufbau auf eine Lochrasterplatine und vor allem für die umfangreichen Verkabelungen der Lötstation muss mit einem Arbeitsaufwand von rund 3 bis 5 Stunden gerechnet werden.

Der Einbau in die 3D-gedruckten Teile geht relativ rasch, einzig für die Lötspitzenhalterung sind einige kleinere Montagearbeiten erforderlich. So muss der Mikroschalter passend fixiert und das metallene Schutzrohr eingepasst und angeklebt (2-Komponenten) werden.

Die folgende Tabelle enthält die erforderlichen elektrischen/elektronischen Komponenten samt Bezugsquellen:

Bezeichnung | Art.Nr. Conrad | Art. Nr. Reichelt
Mikrocontroller ATtiny 84, DIP-14 | - | ATTINY 84V-10-PU/3,02 €
LC-Display 2*16 mit I2C-Bus | | Anmerkung 5 ca. 2,50 €
Drehschalter¹² | | Anmerkung 11 ca. 1,70 €
Sicherungshalter | 533788 1,99 € | PL 125000 0,52 €
Klinkenbuchse 3,5 mm Stereo, z. B.: | 595223 1,59 € | KKMS 35 0,34 €
Transistor IRLML 2060 | 161185 0,23 € | IRLML 2060 0,21 €
Leistungs-MOSFET IRF 7416 | 162476 0,50 € | IRF 7416 0,43 €
Operationsverstärker OPA 336 UA | 1011243 3,49 € | OPA 336 U 2,01 €
Lötspitze Weller RT1 | 588154 42,99 € | WELLER RT 1 39,73 €
Mikroschalter¹³ 20x10x6 mm | | Anmerkung 12 ca. 0,14 €
DC-Buchse 5,5/2,1mm | 1582319 1,19 € | HEBL 21 0,27 €

Tabelle 1: Bauteileliste

Die angeführten Preise sind nur zur Orientierung und entsprechen dem Zeitpunkt der erstmaligen Veröffentlichung.

1 M. Kumm, DC3MKB „Preisgünstige Eigenbau-Lötstation mit SMD-Lötspitze von Weller“, Funkamateur 7/2014

2
http://www.martin-kumm.de/wiki/doku.php?id=Projects:SMD_Loetstation
3 M. Kumm, DC3MKB, Elektor Juli/August 2015

4
http://www.atmel.com/Images/Atmel-7701_Automotive-Microcontrollers-ATtiny24-44-84_Datasheet.pdf
5 Bezugsquelle z.B.: https://www.banggood.com/IIC-I2C-1602-Blue-Backlight-LCD-Display-Module-For-Arduino-p-950726.html (https://www.banggood.com/IIC-I2C-1602-Blue-Backlight-LCD-Display-Module-For-Arduino-p-950726.html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)
6 Standard-Drehschalter, Bezugsquelle z.B.: https://www.banggood.com/Wholesale-12mm-Rotary-Encoder-Switch-with-Key-Switch-with-2-bit-gray-scale-p-41613.html (https://www.banggood.com/Wholesale-12mm-Rotary-Encoder-Switch-with-Key-Switch-with-2-bit-gray-scale-p-41613.html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)
7 Die Druckmodelle können von https://www.thingiverse.com/thing:2521885 oder von der Website des Autors (www.oe1cgs.at) heruntergeladen werden

8
In dem herunterladbaren .zip-File sind sowohl der Quellcode als auch ein direkt verwendbares .hex-File enthalten: http://www.oe1cgs.at/wp-content/uploads/2017/09/Loetstation_V12.zip

9
https://github.com/damellis/attiny
10 http://www.buxtronix.net/2011/10/rotary-encoders-done-properly.html
11 Obwohl für den Einsatzzweck nicht unbedingt erforderlich, wird die verbleibende Nichtlinearität durch die Firmware ausgeglichen.
12 Bezugsquelle z. B.: https://www.banggood.com/Wholesale-12mm-Rotary-Encoder-Switch-with-Key-Switchwith-2-bit-gray-scale-p-41613.html (https://www.banggood.com/Wholesale-12mm-Rotary-Encoder-Switch-with-Key-Switch-with-2-bit-gray-scale-p-41613.html)
13 Bezugsquelle z. B.: https://www.banggood.com/10Pcs-Micro-Limit-Switch-Roller-Lever-5A-125V-Open-Close-Switch-p-945733.html (https://www.banggood.com/10Pcs-Micro-Limit-Switch-Roller-Lever-5A-125V-Open-Close-Switch-p-945733.html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)
Von diesen Schaltern müssen die Rollen durch Abzwicken entfernt werden.

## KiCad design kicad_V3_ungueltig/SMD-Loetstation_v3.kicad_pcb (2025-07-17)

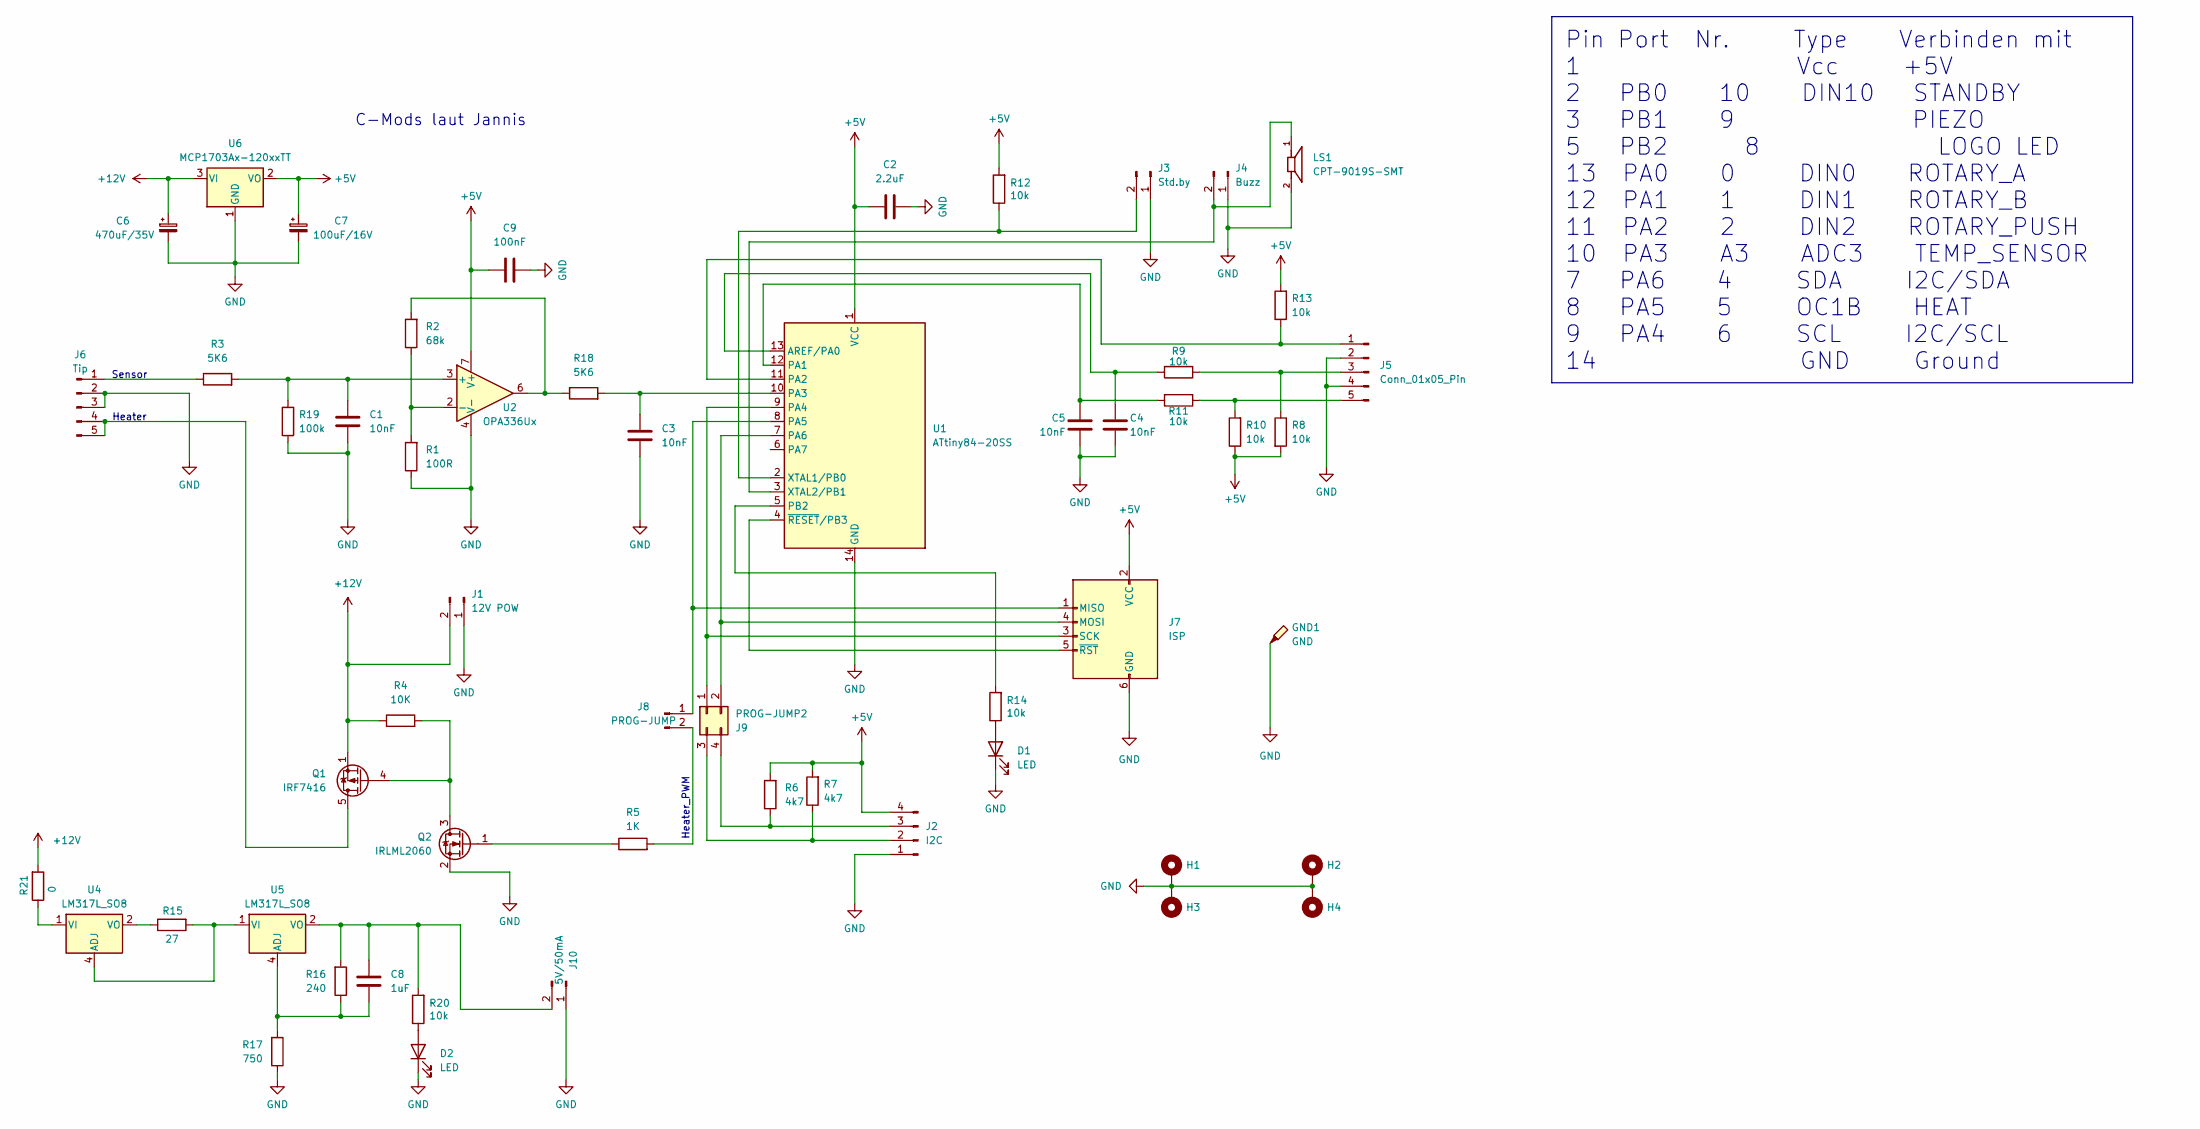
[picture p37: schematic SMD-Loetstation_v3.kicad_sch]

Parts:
C1, C3, C4, C5: 10nF; C_0805_2012Metric_Pad1.18x1.45mm_HandSolder
C2: 2.2uF; C_0805_2012Metric_Pad1.18x1.45mm_HandSolder
C6: 470uF/35V; CP_Elec_10x10.5
C7: 100uF/16V; CP_Elec_6.3x5.4
C8: 1uF; C_0805_2012Metric_Pad1.18x1.45mm_HandSolder
C9: 100nF; C_0805_2012Metric_Pad1.18x1.45mm_HandSolder
D1, D2: LED; LED_0805_2012Metric
GND1: GND; TestPoint_Pad_2.0x2.0mm
H1, H2, H3, H4: MountingHole_Pad; MountingHole_2.5mm_Pad
J1: 12V POW; JST_XH_B2B-XH-A_1x02_P2.50mm_Vertical
J2: I2C; PinHeader_1x04_P2.54mm_Vertical
J3: Std.by; PinHeader_1x02_P2.54mm_Vertical
J4: Buzz; PinHeader_1x02_P2.54mm_Vertical
J5: Conn_01x05_Pin; PinHeader_1x05_P2.54mm_Vertical
J6: Tip; JST_XH_B5B-XH-A_1x05_P2.50mm_Vertical
J7: ISP; PinHeader_2x03_P2.54mm_Vertical
J8: PROG-JUMP; PinHeader_1x02_P2.54mm_Vertical
J9: PROG-JUMP2; PinHeader_2x02_P2.54mm_Vertical
J10: 5V/50mA; PinHeader_1x02_P2.54mm_Vertical
LS1: CPT-9019S-SMT; CUI_CPT-9019S-SMT; PART_REV 1.0
Q1: IRF7416; SOIC-8_3.9x4.9mm_P1.27mm
Q2: IRLML2060; SOT-23
R1: 100R; R_0805_2012Metric_Pad1.20x1.40mm_HandSolder
R2: 68k; R_0805_2012Metric_Pad1.20x1.40mm_HandSolder
R3, R18: 5K6; R_0805_2012Metric_Pad1.20x1.40mm_HandSolder
R4: 10K; R_0805_2012Metric_Pad1.20x1.40mm_HandSolder
R5: 1K; R_0805_2012Metric_Pad1.20x1.40mm_HandSolder
R6, R7: 4k7; R_0805_2012Metric_Pad1.20x1.40mm_HandSolder
R8, R9, R10, R11, R12, R13, R14, R20: 10k; R_0805_2012Metric_Pad1.20x1.40mm_HandSolder
R15: 27; R_0805_2012Metric_Pad1.20x1.40mm_HandSolder
R16: 240; R_0805_2012Metric_Pad1.20x1.40mm_HandSolder
R17: 750; R_0805_2012Metric_Pad1.20x1.40mm_HandSolder
R19: 100k; R_0805_2012Metric_Pad1.20x1.40mm_HandSolder
R21: 0; R_0805_2012Metric_Pad1.20x1.40mm_HandSolder
U1: ATtiny84-20SS; SOIC-14_3.9x8.7mm_P1.27mm
U2: OPA336Ux; SO-8_3.9x4.9mm_P1.27mm
U4, U5: LM317L_SO8; SOIC-8_3.9x4.9mm_P1.27mm
U6: MCP1703Ax-120xxTT; SOT-23_Handsoldering

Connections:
+5V: C2.1, C7.1, C9.1, J2.4, J7.2 (VCC), R6.2, R7.2, R8.2, R10.1, R12.2, R13.2, U1.1 (VCC), U2.7 (V+), U6.2 (VO); also elsewhere on the board
+12V: C6.1, J1.2, Q1.1 (S), Q1.2 (S), Q1.3 (S), R4.1, R21.2, U6.3 (VI); also elsewhere on the board
GND: C1.2, C2.2, C3.2, C4.2, C5.1, C6.2, C7.2, C9.2, D1.1 (K), D2.1 (K), GND1.1, H1.1, H2.1, H3.1, H4.1, J1.1, J2.1, J3.1, J4.1, J5.2, J5.4, J6.2, J6.3, J7.6 (GND), J10.1, LS1.2, Q2.2 (S), R1.1, R17.1, R19.1, U1.14 (GND), U2.4 (V-), U6.1 (GND); also elsewhere on the board
unnamed: D1.2 (A), R14.1
unnamed: D2.2 (A), R20.1
unnamed: J2.2, J9.3, R7.1
unnamed: J2.3, J9.4, R6.1
unnamed: J3.2, R12.1, U1.2 (XTAL1/PB0)
unnamed: J4.2, LS1.1, U1.3 (XTAL2/PB1)
unnamed: J5.1, R13.1, U1.11 (PA2)
unnamed: J5.3, R8.1, R9.1
unnamed: J5.5, R10.2, R11.1
unnamed: J6.1, R3.1
unnamed: J6.4, J6.5, Q1.5 (D), Q1.6 (D), Q1.7 (D), Q1.8 (D)
unnamed: J7.1 (MISO), J8.1, U1.8 (PA5)
unnamed: J7.4 (MOSI), J9.2, U1.7 (PA6)
unnamed: J7.3 (SCK), J9.1, U1.9 (PA4)
unnamed: J7.5 (~RST), U1.4 (~RESET/PB3)
unnamed: J8.2, R5.2
unnamed: C8.1, J10.2, R16.2, R20.2, U5.2 (VO), U5.3 (VO), U5.6 (VO), U5.7 (VO)
unnamed: Q1.4 (G), Q2.3 (D), R4.2
unnamed: Q2.1 (G), R5.1
unnamed: R15.1, U4.2 (VO), U4.3 (VO), U4.6 (VO), U4.7 (VO)
unnamed: R2.2, R18.1, U2.6
unnamed: C4.1, R9.2, U1.13 (AREF/PA0)
unnamed: C5.2, R11.2, U1.12 (PA1)
unnamed: C3.1, R18.2, U1.10 (PA3)
unnamed: R14.2, U1.5 (PB2)
unnamed: C1.1, R3.2, R19.2, U2.3 (+)
unnamed: R1.2, R2.1, U2.2 (-)
unnamed: R15.2, U4.4 (ADJ), U5.1 (VI)
unnamed: R21.1, U4.1 (VI)
unnamed: C8.2, R16.1, R17.2, U5.4 (ADJ)

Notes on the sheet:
Pin Port Nr. Type Verbinden mit 1 Vcc +5V 2 PB0 10 DIN10 STANDBY 3 PB1 9 PIEZO 5 PB2 8 LOGO LED 13 PA0 0 DIN0 ROTARY_A 12 PA1 1 DIN1 ROTARY_B 11 PA2 2 DIN2 ROTARY_PUSH 10 PA3 A3 ADC3 TEMP_SENSOR 7 PA6 4 SDA I2C/SDA 8 PA5 5 OC1B HEAT 9 PA4 6 SCL I2C/SCL 14 GND Ground
Heater
Sensor
C-Mods laut Jannis
Heater_PWM

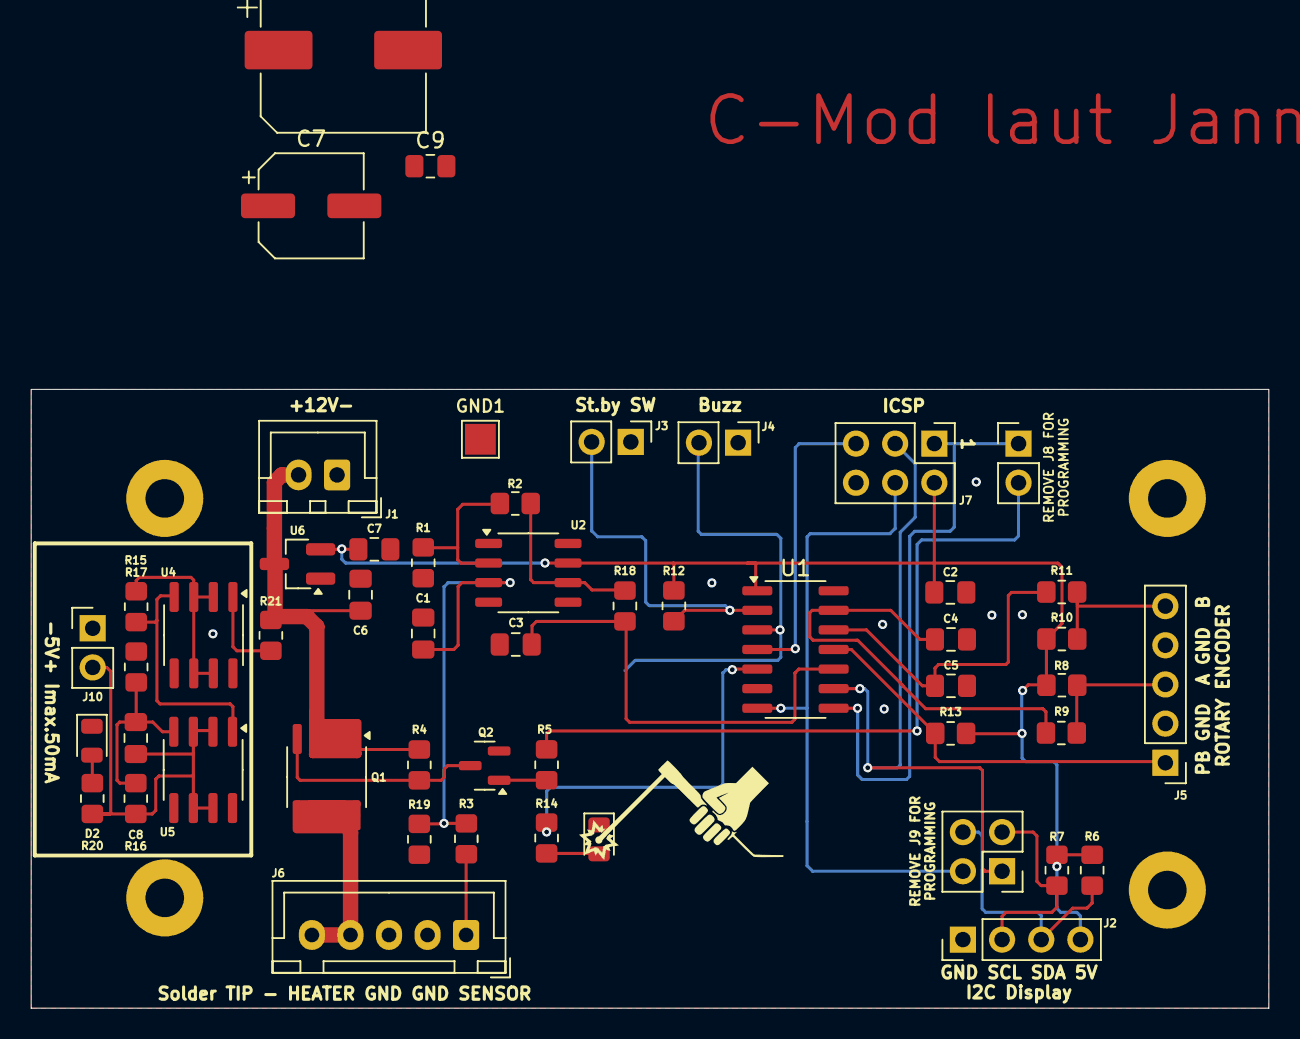
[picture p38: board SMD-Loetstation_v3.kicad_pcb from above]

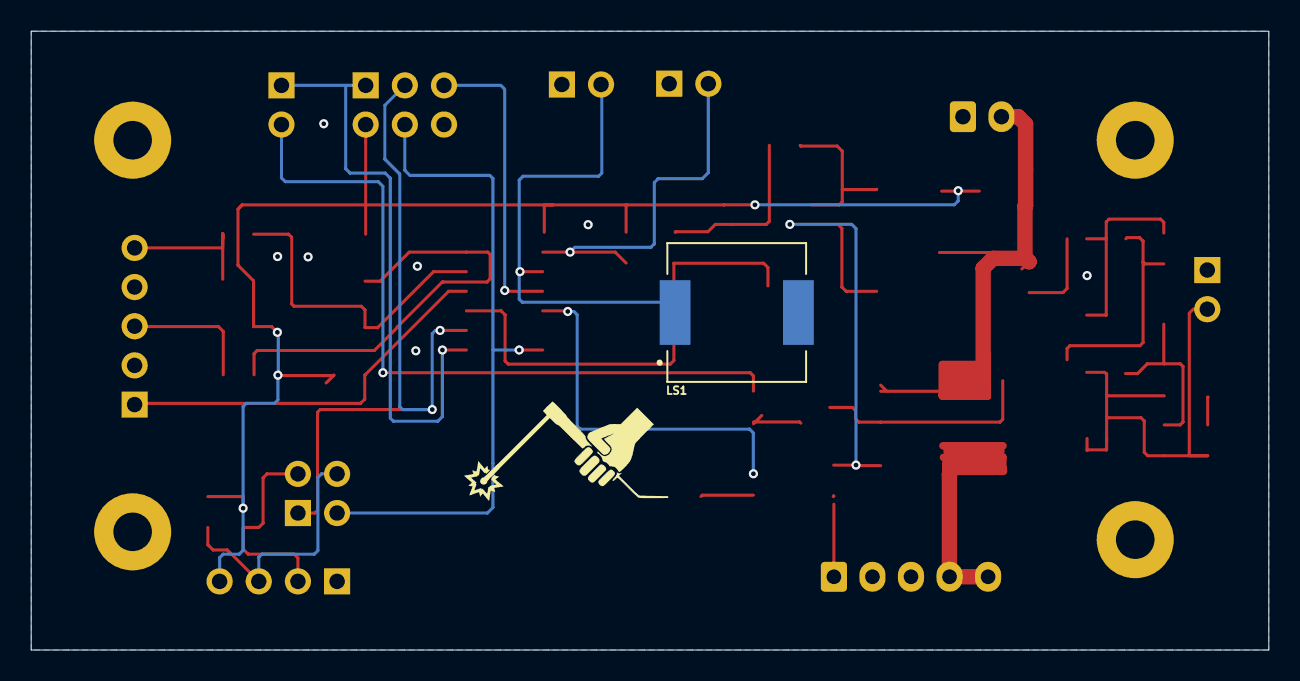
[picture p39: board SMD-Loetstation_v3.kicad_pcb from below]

Board: 2 copper layers, 80.3 x 40.1 mm, 59 parts (2 on the bottom side), 33 nets.

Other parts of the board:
C6#2, C7#2: 1uF; C_0805_2012Metric_Pad1.18x1.45mm_HandSolder
G10, G10#2: LOGO

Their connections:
+5V: C7#2.1; also elsewhere on the board
+12V: C6#2.1; also elsewhere on the board
GND: C6#2.2, C7#2.2; also elsewhere on the board

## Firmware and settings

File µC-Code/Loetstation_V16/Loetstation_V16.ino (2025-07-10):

/* Loetstation copyright (C) 2017 OE1CGS Chris
 *
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
   Firmware fuer ATtiny84
   Pin-Belegung:    Pin  Port   Nr.	    Type    Verbinden mit
                     1                  Vcc     +5V
                     2   PB0    10      DIN10   STANDBY
                     3   PB1    9               PIEZO
                    13   PA0    0       DIN0    ROTARY_A
                    12   PA1    1       DIN1    ROTARY_B
                    11   PA2    2       DIN2    ROTARY_PUSH
                    10   PA3    A3      ADC3    TEMP_SENSOR
                     7   PA6    4       SDA     I2C/SDA
                     8   PA5    5       OC1B    HEAT
                     9   PA4    6       SCL     I2C/SCL
                    14                  GND     Ground

                    
   Compiler:     ATtiny Core by David Mellis, https://github.com/damellis/attiny
   Taktfrequenz: Intern 1 MHz
   Autor:        Christoph Schwaerzler, OE1CGS
   Version:      1.2  vom 27.07.2017
   Version       1.3 vom 19.10.2024 / OE9SAU
                 *Pin-Belegung: 
                  Pin Port Nr.
                   5  PB2  8   LOGO LED
                 *Programmanpassung für LOGO LED
                 1.4 vom 04.04.25/ OE9SAU
                 *STEP 346: 4000 auf 2500ms 
                 1.5 vom 15.04.2025
                 *flackerLogoLED ohne delay
                 *NOTAUSDIFF von 50 auf 30
                 *NOTAUSANZ von 10 auf 5
				 1.6 vom 10.07.2025
                 *NOTAUSDIFF von 30 auf 50
                 *NOTAUSANZ von 5 auf 10
*/

#include <TinyWireM.h>
#include <LiquidCrystal_I2C.h>
#include <EEPROM.h>

#define PIN_ROT_A    0                                // IC-Pin 13 ist der Anschluss fuer den Drehschalter-Ausgang A
#define PIN_ROT_B    1                                // IC-Pin 12 ist der Anschluss fuer den Drehschalter-Ausgang B
#define PIN_ROT_PUSH 2                                // IC-Pin 11 ist der Anschluss fuer den Drehschalter-Drucktaster
#define PIN_HEAT     5                                // IC-Pin 8 ist als OC1B PWM-faehig (Timer1, da Timer0 bereits fuer delay())
#define PIN_TEMP     A3                               // IC-Pin 10 ist der Anschluss (=ADC) fuer den Temperatursensor
#define PIN_STBY     10                               // IC-Pin 2 ist der Anschluss fuer den Standby-Schalter gegen Masse
#define PIN_PIEZO    9                                // IC-Pin 3 als Ausgang zur Ansteuerung des Piezos
#define PIN_LED      8                                // IC-Pin 5 ist der Anschluss fuer die LOGO-FLACKER-LED
#define LCDI2CADR    0x27                             // I2C-Adresse des LCD-Bausteins (typ. 0x27 oder 0x3F), I2C Scanner benutzen
#define WARTEZEIT    10                               // Wartezeit zwischen Abschaltung Heizung und Temperaturmessung in ms
#define REGELZEIT    100                              // Zeitintervall zwischen Regelprozessen in ms; muss >= 30 sein
#define A_ADC        -0.000155                        // Koeffizient des quadratrischen Terms im Zusammenhang zwischen ADC-Wert und IST-Temperatur -0.000151
#define B_ADC        0.533                            // Koeffizient des linearen Terms im Zusammenhang zwischen ADC-Wert und IST-Temperatur       0.533
#define C_ADC        37.40                            // Offset des quadratischen Zusammenhangs zwischen ADC-Wert und IST-Temperatur               37.40
#define W_AKT        0.7                              // Gewicht des aktuellen Temperaturwertes bei der laufenden Mittelwertbildung                0.7
#define P_KOEFF_P    7                                // Koeffizient des P-Reglers; VORSICHT: Darf maximal einen Wert von 30 annehmen, sonst Int-Problem im Regler
#define P_KOEFF_PID  9.0
#define I_KOEFF_PID  0.2
#define D_KOEFF_PID  19.5
#define T_MIN        50                               // Minimal erlaubte Temperatureinstellung in Grad Celsius
#define T_MAX        400                              // Maximal erlaubte Temperatureinstellung in Grad Celsius
#define PRELLUNG     10                               // Wartezeit fuer Entprellung des Tasters in Millisekunden
#define TONPEAKZEIT  70                               // Dauer einer Schwingung in Mikrosekunden
#define TONEINZEIT   1000                             // Dauer des Tons als Anzahl der Schwingungen
#define TONEINDIFF   4                                // Temperaturdifferenz SOLL/IST in Grad C bei der ein Ton ertoent
#define TONRESDIFF   10                               // Temperaturdifferenz SOLL/IST in Grad C fuer reset, um spaeter wieder zu ertoenen
#define NOTAUSDIFF   50                               // Abweichung vom letzten (sinnvollen) Wert, ab welcher ein Wert als ungueltig betrachtet wird
#define NOTAUSANZ    10                                // Anzahl der direkt aufeinanderfolgenden, ungueltigen Werte, bevor NOTAUS erfolgt

LiquidCrystal_I2C lcd(LCDI2CADR, 2, 1, 0, 4, 5, 6, 7, 3, POSITIVE); // Instanz "lcd" erzeugen und LCD-Anzeige initialisieren

byte          curpos  =  1;                           // Position des Cursors; Wertemenge = {1,2,3,4,5}
byte          unguelt =  0;                           // Anzahl der aufeinanderfolgenden, ungueltigen Temperaturwerte
int           a_tist  =  0; int   l_tist  = 0;        // Aktuelle (a_tist)  bzw. letzte (l_tist)  IST  - Temperatur in Grad Celsius
int           a_tsoll = 60; int   l_tsoll = 0;        // Aktuelle (a_tsoll) bzw. letzte (l_tsoll) SOLL - Temperatur in Grad Celsius
int           anz_tist;     int   lanz_tist;          // Geglaettet, angezeigte aktuelle (anz_tist)  bzw. letzte (lanz_tist)  IST  - Temperatur
int           lr_tist;                                // Letzte Temperatur fuer PID-Regler;
int           tstby   = 60;                           // Standby-Temperatur in Grad Celsius
int           tset1;                                  // SET 1 - Temperatur in Grad Celsius
int           tset2;                                  // SET 2 - Temperatur in Grad Celsius
int           tset3;                                  // SET 3 - Temperatur in Grad Celsius
int           pwm     =   0;                          // Aktueller Heizwert fuer PWM-Register; Wertebereich = [0,1023]
int           anzdreh =   0;                          // Anzahl Drehschritte nach rechts (+) oder links (-) seit letzter Abfrage
boolean       standby =   false;                      // Zwischenspeicher fuer den a_tsoll Wert, solange im Standby-Modus
boolean       ton     =   true;                       // Zeigt an, ob Tonsignal ein (=true) oder ausgeschalten ist
boolean       set_ton =   false;                      // War schon einmal ein Ton, bevor er zurueckgesetzt wurde?
boolean       lnotaus =   false;                      // War beim letzten Reglerdurchgang auch schon ein Problem?
unsigned long lzp_regler = 0;                         // Letzter Zeitpunkt zu dem der Regler nachgestellt wurde
volatile byte dstatus= 0;                             // Letzter Zustand des Drehschalters
const byte    dtabelle[7][4] = {                      // Dies ist die Zustandstabelle fuer den Drehschalter
  {0x0, 0x2, 0x4,  0x0}, {0x3, 0x0, 0x1, 0x10},       // Kredit geht dafuer an Ben Buxton 2011 mit seiner "Rotary" library
  {0x3, 0x2, 0x0,  0x0}, {0x3, 0x2, 0x1,  0x0},
  {0x6, 0x0, 0x4,  0x0}, {0x6, 0x5, 0x0, 0x20},
  {0x6, 0x5, 0x4,  0x0}};
byte backchar[8]={                                    // Beschreibung des selbstdefinierten Symbols "Zurueck"
  0x04,0x0E,0x1F,0x04,0x04,0x1C,0x00,0x00};
byte stbychar[8]={                                    // Beschreibung des selbstdefinierten Symbols "Standby"
  0x00,0x0E,0x15,0x17,0x11,0x0E,0x00,0x00};
byte settchar[8]={                                    // Beschreibung des selbstdefinierten Symbols "Settemp"
  0x00,0x04,0x06,0x1F,0x1F,0x06,0x04,0x00};
byte tonschar[8]={                                    // Beschreibung des selbstdefinierten Symbols "Ton"
  0x01,0x03,0x0f,0x0f,0x0f,0x03,0x01,0x00};
byte wellchar[8]={                                    // Beschreibung des selbstdefinierten Symbols "Wellen"
  0x04,0x08,0x10,0x1c,0x10,0x08,0x04,0x00};

unsigned long letzteFlackerZeit = 0;
int flackerDelay = 0;

void setup(){
  OSCCAL = 0x83;                                      // Kalibrierung des internen Oszillators, z.B. TinyTuner benutzen
  pinMode(PIN_ROT_A,    INPUT_PULLUP);                // IC-Pin 13 als Eingang mit Pullup-Widerstand definieren (Drehschalter A)
  pinMode(PIN_ROT_B,    INPUT_PULLUP);                // IC-Pin 12 als Eingang mit Pullup-Widerstand definieren (Drehschalter B)
  pinMode(PIN_ROT_PUSH, INPUT_PULLUP);                // IC-Pin 11 als Eingang mit Pullup-Widerstand definieren (Drehschalter Taster)
  pinMode(PIN_STBY,     INPUT_PULLUP);                // IC-Pin 2 als Eingang mit Pullup-Widerstand definieren (optionaler Standby-Taster)
  pinMode(PIN_HEAT,     OUTPUT);                      // IC-Pin 8 als Ausgang zur Schaltung der Heizung (PWM)
  pinMode(PIN_PIEZO,    OUTPUT);                      // IC-Pin 3 als Ausgang zur Ansteuerung des Piezos
  pinMode(PIN_LED,      OUTPUT);                      // IC-Pin 5 ist der Anschluss fuer die LOGO-FLACKER-LED
  eepromRead();                                       // Holt die SET-Temperaturen aus dem EEPROM
  if(tset1 == -1){                                    // Beim erstmaligen Aufruf des Programms ist das EEPROM noch leer,
    tset1 = 220;                                      // daher werden die SET-Temperaturen und Ton auf Standardwerte gesetzt
    tset2 = 260;                                      // hier sind die Standardtemperaturen fuer Sn62Pb36Ag2 mit Ts = 179 Grad C optimiert
    tset3 = 300;
    ton   = true;}
  TCCR1A = 0b00100011;                                // 10-bit PWM => 1023 als Maximalwert (=100% Heizung), toggle OC1B
  TCCR1B = 0b00000001;                                // Timer 1 ein, kein Prescaler => 1 MHz -> 496 Hz
  OCR1B  = 0;                                         // Heizung aus (= Duty Cycle 0%)
  GIMSK  |= 0b00010000;                               // Setzt PCIE0 bit (Pin Change Interrupt Enable 0) fuer Drehschalter Interrupt
  PCMSK0 |= 0b00000011;                               // Erlaubt PCINT0 (=Pin 13) und PCINT1 (=Pin 12) einen Pin-Change Interrupt
  sei();                                              // Erlaubt Interrupts
  lcd.begin(16,2);                                    // Starte LCD-Anzeige mit 16 Zeichen in 2 Zeilen
  lcd.createChar(1, backchar);                        // Erzeuge das Symbol "Zurueck" und weise ihm den Code 1 zu
  lcd.createChar(2, stbychar);                        // Erzeuge das Symbol "Standby" und weise ihm den Code 2 zu
  lcd.createChar(3, settchar);                        // Erzeuge das Symbol "Settemp" und weise ihm den Code 3 zu
  lcd.createChar(4, tonschar);                        // Erzeuge das Symbol "Ton"     und weise ihm den Code 4 zu
  lcd.createChar(5, wellchar);                        // Erzeuge das Symbol "Wellen"  und weise ihm den Code 5 zu
  lcd.clear();                                        // Loesche LCD-Anzeige
  lr_tist = abfrageTemperatur();                      // Letzten Temperaturwert auf aktuelle Temperatur setzen
  anz_tist = lr_tist;                                 // Startwert fuer die laufende Mittelwertbildung
  if(!digitalRead(PIN_ROT_PUSH)){schirmSetup();}      // Bei gedruecktem Taster zur Einstellung der Standardwerte
  else{
    lcd.print("SolderUnit V1.6");                     // Begruessungstext 1. Zeile
    lcd.setCursor(0,1);                               // Setze Cursor zum Beginn der zweiten Zeile
    lcd.print("by OE1CGS/OE9SAU");                    // Begruessungstext 2. Zeile
    delay(1500);}                                     // Begruessungstext 1,5 Sekunden lang anzeigen
  eepromUpdate();                                     // Schreibt ggf. geanderte SET-Temperaturen ins EEPROM
  schirmStdinit();                                    // Maske fuer den Standardschirm
}


void loop(){
  reglerTemperatur();                                 // Regelkreis fuer die Loetspitze
  anzeigeTemperatur();                                // Aktualisiert die Temperaturwerte auf der Anzeige
  aendereTemperatur();                                // Aendert ggf. Solltemperatur
  bewegeCursor();                                     // Aendert die Position des Cursors bei Betaetigung des Drehschalters
  waehleSettemperatur();                              // Aendert ggf. Solltemperatur auf eine SET-Temperatur
  standbyAbfrage();                                   // Prueft, ob Standby-Modus aktiviert ist
  flackerLogoLED();                                   // LOGO-FLACKER-LED
}

void flackerLogoLED() {
  if (pwm > 10) {
    unsigned long aktuelleZeit = millis();

    if (aktuelleZeit - letzteFlackerZeit >= flackerDelay) {
      letzteFlackerZeit = aktuelleZeit;
      flackerDelay = random(100, 400);
      analogWrite(8, random(100, 256));
    }
  }
}

void schirmStdinit(){                                 // Maske fuer den Standardbildschirm
  lcd.clear();                                        // Sie wird nur einmalig beim Hochstarten erzeugt; in weiterer Folge
  lcdPrint3d(anz_tist);lanz_tist = anz_tist;          // werden nur die aktuelle Temperatur sowie gegebenenfalls die Solltemperatur
  lcd.print("\337C     ");                            // und der Cursor aktualisiert
  lcd.print(char(3));                                 // Zeige das selbsterstellte Symbol fuer "Settemp" an
  lcdPrint3d(a_tsoll);l_tsoll = a_tsoll;
  lcd.print("\337C");                                 // Der Code \337 erzeugt das "Grad" Symbol
  lcd.setCursor(0,1);
  lcdPrint3d(tset1);
  lcd.print("\337  ");
  lcdPrint3d(tset2);
  lcd.print("\337 ");
  lcdPrint3d(tset3);
  lcd.print("\337C");
  curpos = 1;                                         // setze den Cursor fuer den Hauptschirm auf die Settemperatur
  lcd.setCursor(13,0);
  lcd.cursor();                                       // Zeigt den Cursor an
}


void anzeigeTemperatur(){                             // Standardschirm: In dieser Funktion werden nur die aktuelle Temperaturanzeige
  anz_tist = W_AKT * a_tist + (1-W_AKT) * anz_tist;   // Anzeigewert ist der laufende, gewichtete Mittelwert
  if(anz_tist != lanz_tist){                          //   sowie gegebenenfalls die Solltemperatur und die Cursorposition/blinken
    lcd.setCursor(0,0);                               //   aktualisiert.
    lcdPrint3d(anz_tist);lanz_tist = anz_tist;        // Eine Aktualisierung erfolgt nur einmalig, wenn sich der Wert veraendert,
    setCurpos();                                      // Setzt den Cursor wieder an die richtige Stelle
    if(abs(a_tsoll-anz_tist) <= TONEINDIFF && !set_ton){// Wenn sich die Temperatur geaendert hat, koennte es auch sein, dass der Pizeo laeuten soll
      if(ton){ringPiezo(TONPEAKZEIT, TONEINZEIT);}    // ...aber nur, wenn Tonsignal eingeschalten ist
      set_ton = true;                                 // Jetzt soll es aber vorerst nicht mehr laeuten
    }
    if(abs(a_tsoll-anz_tist) >= TONRESDIFF){          // Erst wenn die Differenz wieder gross wurde (z.B. bei einem Standby-Betrieb) soll es wieder laeuten
      set_ton = false;
    }
  }
  if(a_tsoll != l_tsoll){
    lcd.setCursor(11,0);
    lcdPrint3d(a_tsoll);l_tsoll = a_tsoll;
    setCurpos();                                      // Setzt den Cursor wieder an die richtige Stelle
  }
}


void aendereTemperatur(){                             // Funktion zur Aenderung der aktuellen Solltemperatur bei Druck auf Drehschalter und folgender Drehung
  if(digitalRead(PIN_ROT_PUSH) || curpos > 1){return;}// Wenn der Taster nicht gedrueckt wird, oder auf SET-Wert steht sind wir hier schon fertig
  warten(PRELLUNG);                                   // Entprellung des Tasters
  while(!digitalRead(PIN_ROT_PUSH)){
    reglerTemperatur();                               //   ...aber die wichtigen Prozesse der Temperaturregelung und
    anzeigeTemperatur();                              //   ...der Anzeige der korrekten Temperaturen und
    standbyAbfrage();                                 //   ...der Check, ob Standby aktiv ist muessen fortgesetzt werden
    if(anzdreh != 0){
      a_tsoll = a_tsoll + anzdreh;                    // Anpassung von a_tsoll um die Drehbewegung des Drehschalters (1 Raster = 1 Grad Celsius)
      anzdreh = 0;                                    // Drehungswert zurueck setzen
      a_tsoll = min(max(a_tsoll,T_MIN),T_MAX);        // Schraenkt den Wertebereich der Solltemperatur auf T_MIN bis T_MAX ein
    }
  }
  warten(PRELLUNG);                                   // Nachdem der Taster losgelassen wurde, muss noch die Entprellung abgewartet werden
}


void bewegeCursor(){                                  // Aendert die Cursorposition, wenn der Drehschalter gedreht wird
  if(anzdreh != 0){                                   // Code nur ausfuehren, wenn der Drehschalter betaetigt wurde
  curpos = curpos + anzdreh;                          // Cursorposition um Bewegung des Drehschalters veraendern
    anzdreh = 0;                                      // Drehungswert zurueck stellen
    curpos = min(max(curpos,1),4);                    // Schraenkt den Wertebereich von curpos auf 1 bis 4 ein
    setCurpos();                                      // Setzt den Cursor wieder an die richtige Stelle
  }
}


void waehleSettemperatur(){                           // Macht die gewaehlte SET-Temperatur zur Solltemperatur
  if(digitalRead(PIN_ROT_PUSH) || curpos == 1){return;}       // Code wird nur ausgefuehrt, wenn Drehtaster gedrueckt wird waehrend Cursor auf einer Set-Temperatur
    switch(curpos){                                   // Ermittelt die Settemperatur auf der Anzeige abhaengig vom Wert von curpos
      case 1: break;                                  //    und weist diese der Solltemperatur zu
      case 2: a_tsoll = tset1; break;
      case 3: a_tsoll = tset2; break;
      case 4: a_tsoll = tset3; break;}
  warten(PRELLUNG);                                   // Warten auf Entprellung des Tasters
  while(!digitalRead(PIN_ROT_PUSH)){                  // Taster muss losgelassen werden bevor weitere Aktionen erfolgen koennen
    reglerTemperatur();                               //   ...aber die wichtigen Prozesse der Temperaturregelung und
    anzeigeTemperatur();                              //   ...der Anzeige der korrekten Temperatur und
    standbyAbfrage();}                                //   ...der Check, ob Standby aktiv ist muessen fortgesetzt werden
  warten(PRELLUNG);                                   // Warten auf Entprellung des Tasters
  curpos = 1;                                         // Nach Abschluss wird der Cursor wieder auf die Solltemperatur gestellt
  lcd.setCursor(13,0);                                //    und dort angezeigt
}


void schirmSetup(){                                   // Bildschirm zur Einstellung der Standardwerte; wird nur bei gedrueckte Taste aufgerufen
  lcd.print("Standard:  ");
  lcd.print(char(4));                                 // Stellt das Symbol "Ton" dar
  if(ton){lcd.print(char(5));}                        // Wenn Ton ein, stelle auch das Symbol "Wellen" dar
  else{lcd.print(" ");}                               //   sonst stelle nur ein Leerzeichen dar
  lcd.print("  ");
  lcd.print(char(1));                                 // Stellt das Symbol "Zurueck" dar
  lcd.setCursor(0,1);
  lcdPrint3d(tset1);
  lcd.print("\337  ");
  lcdPrint3d(tset2);
  lcd.print("\337 ");
  lcdPrint3d(tset3);
  lcd.print("\337C");
  lcd.cursor();                                       // Stellt den Cursor dar
  warten(PRELLUNG);                                   // Warten auf Entprellung des Tasters
  while(!digitalRead(PIN_ROT_PUSH))                   // Taster muss losgelassen werden bevor weitere Aktionen erfolgen koennen
  warten(PRELLUNG);                                   // Warten auf Entprellung des Tasters
  while (digitalRead(PIN_ROT_PUSH) || curpos != 2){   // Erst wenn Cursor auf "Ende" steht und Taster gedrueckt wird zurueck
    curpos = curpos + anzdreh;                        // Cursorposition um Bewegung des Drehschalters veraendern
    anzdreh = 0;                                      // Drehungswert zurueck stellen
    curpos = min(max(curpos,1),5);                    // Schraenkt den Wertebereich von curpos auf 1 bis 4 ein
    switch(curpos){                                   // Ermittelt die Cursorposition auf der Anzeige abhaengig vom Wert von curpos
      case 1:  lcd.setCursor(12,0); break;                             
      case 2:  lcd.setCursor(15,0); break;
      case 3:  lcd.setCursor( 2,1); break;
      case 4:  lcd.setCursor( 8,1); break;
      case 5:  lcd.setCursor(13,1); break;}
    while(!digitalRead(PIN_ROT_PUSH) && curpos != 2){
      warten(PRELLUNG);  
      if(anzdreh != 0){
        switch(curpos){
          case 1: ton = !ton;   lcd.setCursor(12,0);
                  if(ton){lcd.print(char(5));}
                  else{lcd.print(" ");}
                  lcd.setCursor(12,0); break;
          case 3: lcd.setCursor( 0,1);                 // Aendert den angezeigten Wert der soeben adjustierten SET-Temperatur
            tset1 = min(max(tset1+anzdreh,T_MIN),T_MAX);
            lcdPrint3d(tset1);   lcd.setCursor( 2,1);
            break;
          case 4: lcd.setCursor( 6,1);
            tset2 = min(max(tset2+anzdreh,T_MIN),T_MAX);
            lcdPrint3d(tset2);   lcd.setCursor( 8,1);
            break;
          case 5: lcd.setCursor(11,1);
            tset3 = min(max(tset3+anzdreh,T_MIN),T_MAX);
            lcdPrint3d(tset3);   lcd.setCursor(13,1);
            break;}
        anzdreh = 0;                                   // Drehungswert zurueck setzen
        }
     }
     warten(PRELLUNG);
   }
}
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

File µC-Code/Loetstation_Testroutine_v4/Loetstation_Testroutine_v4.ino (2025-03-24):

//Testroutine für Lötkolben Projekt
//zum Überprüfen der externen Verdrahtung und PCB Bestückung
//v4_OE9SAU_CHATGPT

#include <TinyWireM.h>
#include <LiquidCrystal_I2C.h>

#define LCDI2CADR 0x27
LiquidCrystal_I2C lcd(LCDI2CADR, 2, 1, 0, 4, 5, 6, 7, 3, POSITIVE);

#define PIN_ROT_A    0
#define PIN_ROT_B    1
#define PIN_ROT_PUSH 2
#define PIN_HEAT     5
#define PIN_TEMP     A3
#define PIN_STBY     10
#define PIN_PIEZO    9
#define PIN_LED      8

unsigned long standbyStart = 0;
bool inStandby = false;
int lastRotA = HIGH;

void setup() {
  lcd.begin(16, 2);
  lcd.setBacklight(true);
  lcd.setCursor(0, 0);
  lcd.print("HW TEST v3");

  pinMode(PIN_ROT_A, INPUT_PULLUP);
  pinMode(PIN_ROT_B, INPUT_PULLUP);
  pinMode(PIN_ROT_PUSH, INPUT_PULLUP);
  pinMode(PIN_STBY, INPUT_PULLUP);
  pinMode(PIN_HEAT, OUTPUT);
  digitalWrite(PIN_HEAT, LOW);
  pinMode(PIN_PIEZO, OUTPUT);
  pinMode(PIN_LED, OUTPUT);
  delay(2000);
  lcd.clear();
}

void loop() {
  waitForButtonPress();
  standbyMode();
  
  // Piezo-Test
  lcd.clear();
  lcd.setCursor(0, 0);
  lcd.print("Piezo Test");
  playTone(1000, 500);
  delay(500);
  waitForButtonPress();

  // HEAT-Test mit analoger Spannungsausgabe
  lcd.clear();
  lcd.setCursor(0, 0);
  lcd.print("HEAT Test");
  for (int i = 0; i < 5; i++) {
    lcd.setCursor(5 + i, 0);
    lcd.print(".");
    delay(600);
  }

  // 2V für 2 Sekunden
  analogWrite(PIN_HEAT, 102);  // PWM-Wert für 2V
  delay(2000);  // 2 Sekunden warten

  // 4V für 2 Sekunden
  analogWrite(PIN_HEAT, 204);  // PWM-Wert für 4V
  delay(2000);  // 2 Sekunden warten

  // HEAT ausschalten (Ausgabe auf 0V)
  analogWrite(PIN_HEAT, 0);  // PWM-Wert für 0V
  lcd.clear();
  lcd.setCursor(0, 0);
  lcd.print("HEAT OFF");
  waitForButtonPress();

  // Encoder-Test
  lcd.clear();
  lcd.setCursor(0, 0);
  lcd.print("Encoder Test");
  while (true) {
    int currentRotA = digitalRead(PIN_ROT_A);
    if (currentRotA != lastRotA && currentRotA == LOW) {
      lcd.clear();
      lcd.setCursor(0, 0);
      lcd.print("Encoder Test");
      if (digitalRead(PIN_ROT_B) == LOW) {
        lcd.setCursor(0, 1);
        lcd.print("Dreht RECHTS \76");
      } else {
        lcd.setCursor(0, 1);
        lcd.print("Dreht LINKS  \74");
      }
      delay(500);
    }
    lastRotA = currentRotA;

    if (digitalRead(PIN_ROT_PUSH) == LOW) {  // Bestätigung durch Knopfdruck
      while (digitalRead(PIN_ROT_PUSH) == LOW);  // Warten, bis losgelassen wird
      delay(100);
      break;
    }
  }

  // Test abgeschlossen, Text ausgeben
  lcd.clear();
  lcd.setCursor(0, 0);
  lcd.print("Test Ende");
  while (true);  // Halte den Code an, um das Display anzuzeigen
}

void standbyMode() {
  lcd.clear();
  lcd.setCursor(0, 0);
  lcd.print("Standby Test");
  
  // Zeige den aktuellen Zustand des Standby-Eingangs
  lcd.setCursor(0, 1);
  lcd.print("STBY: " + String(digitalRead(PIN_STBY)));
  
  // LED folgt dem Zustand des Standby-Eingangs
  if (digitalRead(PIN_STBY) == LOW) {
    digitalWrite(PIN_LED, HIGH);  // LED ein, wenn STBY LOW
  } else {
    digitalWrite(PIN_LED, LOW);   // LED aus, wenn STBY HIGH
  }

  standbyStart = millis();
  inStandby = true;

  while (true) {
    // Aktualisiere den Zustand des Standby-Eingangs
    lcd.setCursor(6, 1);
    lcd.print(String(digitalRead(PIN_STBY)) + "  ");
    
    // LED folgt weiterhin dem Zustand des Standby-Eingangs
    if (digitalRead(PIN_STBY) == LOW) {
      digitalWrite(PIN_LED, HIGH);
    } else {
      digitalWrite(PIN_LED, LOW);
    }

    // Warten auf Bestätigung durch Knopfdruck
    if (digitalRead(PIN_ROT_PUSH) == LOW) { 
      while (digitalRead(PIN_ROT_PUSH) == LOW); 
      delay(100);
      break;
    }
  }
  
   inStandby = false;
}

void playTone(int frequency, int duration) {
  int period = 1000000 / frequency;
  int halfPeriod = period / 2;
  unsigned long startMillis = millis();
  while (millis() - startMillis < duration) {
    digitalWrite(PIN_PIEZO, HIGH);
    delayMicroseconds(halfPeriod);
    digitalWrite(PIN_PIEZO, LOW);
    delayMicroseconds(halfPeriod);
  }
}

void waitForButtonPress() {
  lcd.setCursor(0, 1);
  lcd.print("Druecke Knopf...");
  while (digitalRead(PIN_ROT_PUSH) == HIGH);
  while (digitalRead(PIN_ROT_PUSH) == LOW);
  delay(100);
}

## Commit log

2024-10-10 Files Update
    [SMD-Loetstation.kicad_pcb, SMD-Loetstation.kicad_sch]
2024-10-11 Update PCB
    [SMD-Loetstation.kicad_pcb]
2024-10-11 Update pics
    [SMD-Loetstation.kicad_pcb]
2024-10-13 Update PCB 5V
    [SMD-Loetstation.kicad_pcb, SMD-Loetstation.kicad_sch]
2024-10-14 PCB Update
    [SMD-Loetstation-B_Cu.gbr, SMD-Loetstation-B_Mask.gbr, SMD-Loetstation-B_Paste.gbr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]
2024-10-29 Update v1
    some changings on PCB
    [SMD-Loetstation_v1-B_Cu.gbr, SMD-Loetstation_v1-B_Mask.gbr, SMD-Loetstation_v1-B_Paste.gbr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]
2024-10-30 Update MOSFET
    [SMD-Loetstation_v1.kicad_pcb, SMD-Loetstation_v1.kicad_sch]
2024-10-30 Remove old gerber
    [SMD-Loetstation_v1-B_Cu.gbr, SMD-Loetstation_v1-B_Mask.gbr, SMD-Loetstation_v1-B_Paste.gbr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]
2024-10-30 Remove old versions
    [SMD-Loetstation-B_Cu.gbr, SMD-Loetstation-B_Mask.gbr, SMD-Loetstation-B_Paste.gbr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]
2024-11-08 Add v2_all SMD
    [SMD-Loetstation_v2-B_Cu.gbr, SMD-Loetstation_v2-B_Mask.gbr, SMD-Loetstation_v2-B_Paste.gbr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]
2024-11-08 Update Gerber
    [SMD-Loetstation_v2-B_Cu.gbr, SMD-Loetstation_v2-B_Mask.gbr, SMD-Loetstation_v2-B_Paste.gbr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]
2025-03-01 changes V1
    [Rotary_dial_button.stl, Soldering_station_bottom.stl, Soldering_station_top.stl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]
2025-04-03 Update Baumappe
    [Projekt_Lötstation_Stückliste_v2.xlsx]
2025-06-23 PCB v3
    [SMD-Loetstation_v3-B_Cu.gbr, SMD-Loetstation_v3-B_Mask.gbr, SMD-Loetstation_v3-B_Paste.gbr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]

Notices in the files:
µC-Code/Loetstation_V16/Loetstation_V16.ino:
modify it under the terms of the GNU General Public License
